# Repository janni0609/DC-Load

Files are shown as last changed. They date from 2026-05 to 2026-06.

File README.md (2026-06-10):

# DC Electronic Load

A programmable DC electronic load built on the Raspberry Pi Pico 2 (RP2350). It sinks a user-defined current from a DC source under test and measures voltage, current, power, capacity, and energy in real time on a colour TFT display.

## Hardware

| Component | Part | Interface |
|---|---|---|
| MCU | Raspberry Pi Pico 2 (RP2350) | — |
| Display | ILI9488 TFT 240×320 | SPI (GPIO 16/18/19/17/20) |
| DAC (current setpoint) | DAC80501 16-bit | I2C1 0x48 |
| ADC (V + I measurement) | ADS1115 16-bit | I2C1 0x49 |
| I/O expander (buttons/encoder) | TCAL9539 16-bit | I2C1 0x74 |
| Temperature sensors | 3× MCP9700 | ADC (GPIO 26/27/28) |
| Fans | 2× PWM | GPIO 2, 3 (25 kHz) |
| Beeper | — | GPIO 22 |

I2C1 runs on GPIO 14 (SDA) / GPIO 15 (SCL) at 1 MHz.

### Board design

KiCad design files live in [`hardware/`](hardware/):

- [`hardware/PlugInDC Load/`](hardware/PlugInDC%20Load/) — main plug-in board (MCU, DAC/ADC, pass elements, power supply)
- [`hardware/Front Panel/`](hardware/Front%20Panel/) — front panel board

Each project includes the schematic, PCB layout, a schematic PDF, and a STEP model.

## Specifications

| Parameter | Range |
|---|---|
| Input voltage | 0 – 100 V |
| Set current | 0 – 100 A |
| Under-voltage / CV setpoint (UVP) | 0 – 99.99 V |
| Max power (beeper threshold) | 1000 W |

The DAC output (0–2.5 V) drives the current-control circuit: 2.5 V = 100 A full scale. The ADS1115 uses auto-ranging PGA for both channels, scaling 2.5 V → 100 V (voltage) and 2.5 V → 100 A (current).

## Display Layout

Portrait 240×320, divided into sections:

```
┌──────────────────────────┐
│    DC ELECTRONIC LOAD    │  ← green = load ON, yellow = load OFF
├──────────────────────────┤
│ VOLTAGE          xx.xx V │
├──────────────────────────┤
│ CURRENT         x.xxx A  │
├──────────────────────────┤
│ POWER           xxx.xx W │
├──────────────┬───────────┤
│ CAPACITY x.xxx Ah │ x.xx Wh ENERGY │
├──────────────┬───────────┤
│ SET CURR x.x A │ SET UVP xx.xx V │  ← UVP turns red in CV mode
├──────────────┬───────────┤
│ TEMP  xx.x°C │ HH:MM:SS  │
└──────────────┴───────────┘
```

## Controls

All buttons and the rotary encoder are read via the TCAL9539 I/O expander. Button behaviour is context-sensitive: the main screen, debug screen, and calibration screens each respond differently.

### Main screen

| Input | Function |
|---|---|
| Rotary encoder | Increment/decrement the selected digit of the active setpoint |
| P0.0 (encoder push) | Toggle between editing **SET CURR** and **SET UVP** |
| P0.3 | Move cursor left |
| P0.4 | Move cursor right |
| P0.5 | Switch to debug screen |
| P0.6 | Reset elapsed timer and clear Ah/Wh accumulators |
| P0.7 | Toggle internal / external voltage sense |
| P1.0 | Load ON / OFF (blocked while OTP is active) |

### Debug screen

The debug screen is a navigable menu. P0.3/P0.4 move the selection, the encoder adjusts the highlighted item, and P0.0 (encoder push) activates it.

| Menu item | Function |
|---|---|
| I SENSE | Toggle internal / external current shunt (persisted to EEPROM) |
| VOLT CAL | Enter voltage calibration wizard |
| CURR CAL | Enter current calibration wizard |
| VIEW CAL | Display stored calibration tables |
| OTP TRIP | Set over-temperature protection threshold with encoder (persisted) |
| UVP Kp | Adjust UVP PI proportional gain with encoder (persisted) |
| UVP Ki | Adjust UVP PI integral gain with encoder (persisted) |

### Calibration screen

| Input | Function |
|---|---|
| Rotary encoder | Adjust the entered reference value |
| P0.3 / P0.4 | Move digit cursor left / right |
| P0.0 (encoder push) | Confirm step and advance |
| P0.5 | Cancel and return to debug screen |

## UVP / Constant-Voltage Mode

When **SET UVP** is non-zero and the load is on, a software PI controller monitors the measured voltage. If it drops below the UVP setpoint, the controller reduces the sink current to regulate voltage at that level (constant-voltage / CV mode). The SET UVP field turns red while CV mode is active.

CV mode exits with 0.5 V hysteresis to avoid chattering. The PI gains (Kp, Ki) are tunable from the debug screen and stored in EEPROM.

## Over-Temperature Protection (OTP)

The OTP threshold (default 70 °C, adjustable 30–120 °C) is compared against the highest reading across all three MCP9700 sensors. When the threshold is exceeded:

- The load is turned off immediately.
- Five 500 ms beeps are sounded.
- The load ON button is blocked until the temperature drops 5 °C below the threshold.

## Fan Control

Fan speed is temperature-controlled using the highest reading across all three MCP9700 sensors:

- Off below 30 °C
- Linear ramp from 0–100 % between 30 °C and 50 °C
- Full speed above 50 °C

## Calibration

Both voltage and current channels support piecewise-linear calibration (4 points for voltage, 5 for current). The calibration wizard drives the load to each reference point, reads the raw ADC value, and prompts for the reference meter reading. Calibration data is stored in EEPROM and applied on every measurement via `piecewiseLerp`.

### EEPROM layout

| Address | Content |
|---|---|
| 0 | Current shunt select (0x01 = external) |
| 1 | Current cal valid marker (0xCA) |
| 2 | Voltage cal valid marker (0xCA) |
| 3–42 | Current cal: 5× raw + 5× user (10 floats) |
| 43–74 | Voltage cal: 4× raw + 4× user (8 floats) |
| 75 | OTP valid marker (0xCA) |
| 76–79 | OTP threshold (float) |
| 80 | UVP PI valid marker (0xCA) |
| 81–84 | UVP Kp (float) |
| 85–88 | UVP Ki (float) |

## Building

The project uses [PlatformIO](https://platformio.org/) with the Arduino framework.

```bash
# Build
pio run

# Upload
pio run --target upload

# Serial monitor
pio device monitor --baud 115200
```

Target board: `rpipico2`. Dependencies are fetched automatically (`Bodmer/TFT_eSPI`).

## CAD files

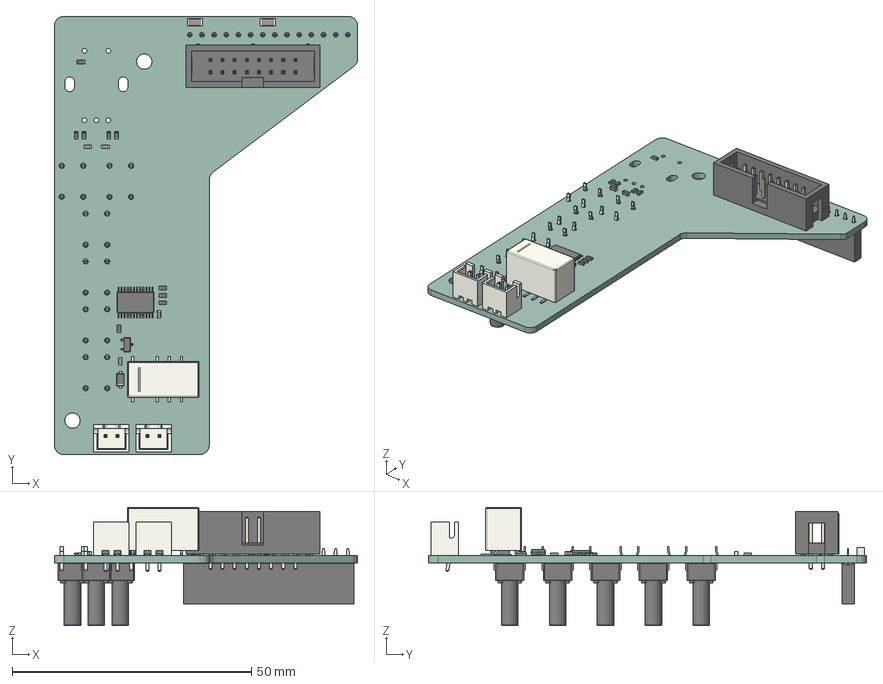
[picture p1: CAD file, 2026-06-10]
hardware/Front Panel/FrontV3.step
63.4 x 91.5 x 24.7 mm
R_0603_1608Metric x 9
JST_XH_B2B-XH-A_1x02_P2.50mm_Vertical x 2
IDC-Header_2x08_P2.54mm_Vertical
C_0603_1608Metric x 4
Relay_DPDT_Kemet_EE2_NU
C_1206_3216Metric x 2
SOT-23
D_SOD-123F
TSSOP-24_4.4x7.8mm_P0.65mm
SW_PUSH_6mm_H13mm x 6
PinSocket_1x14_P2.54mm_Vertical
Front Panel_PCB

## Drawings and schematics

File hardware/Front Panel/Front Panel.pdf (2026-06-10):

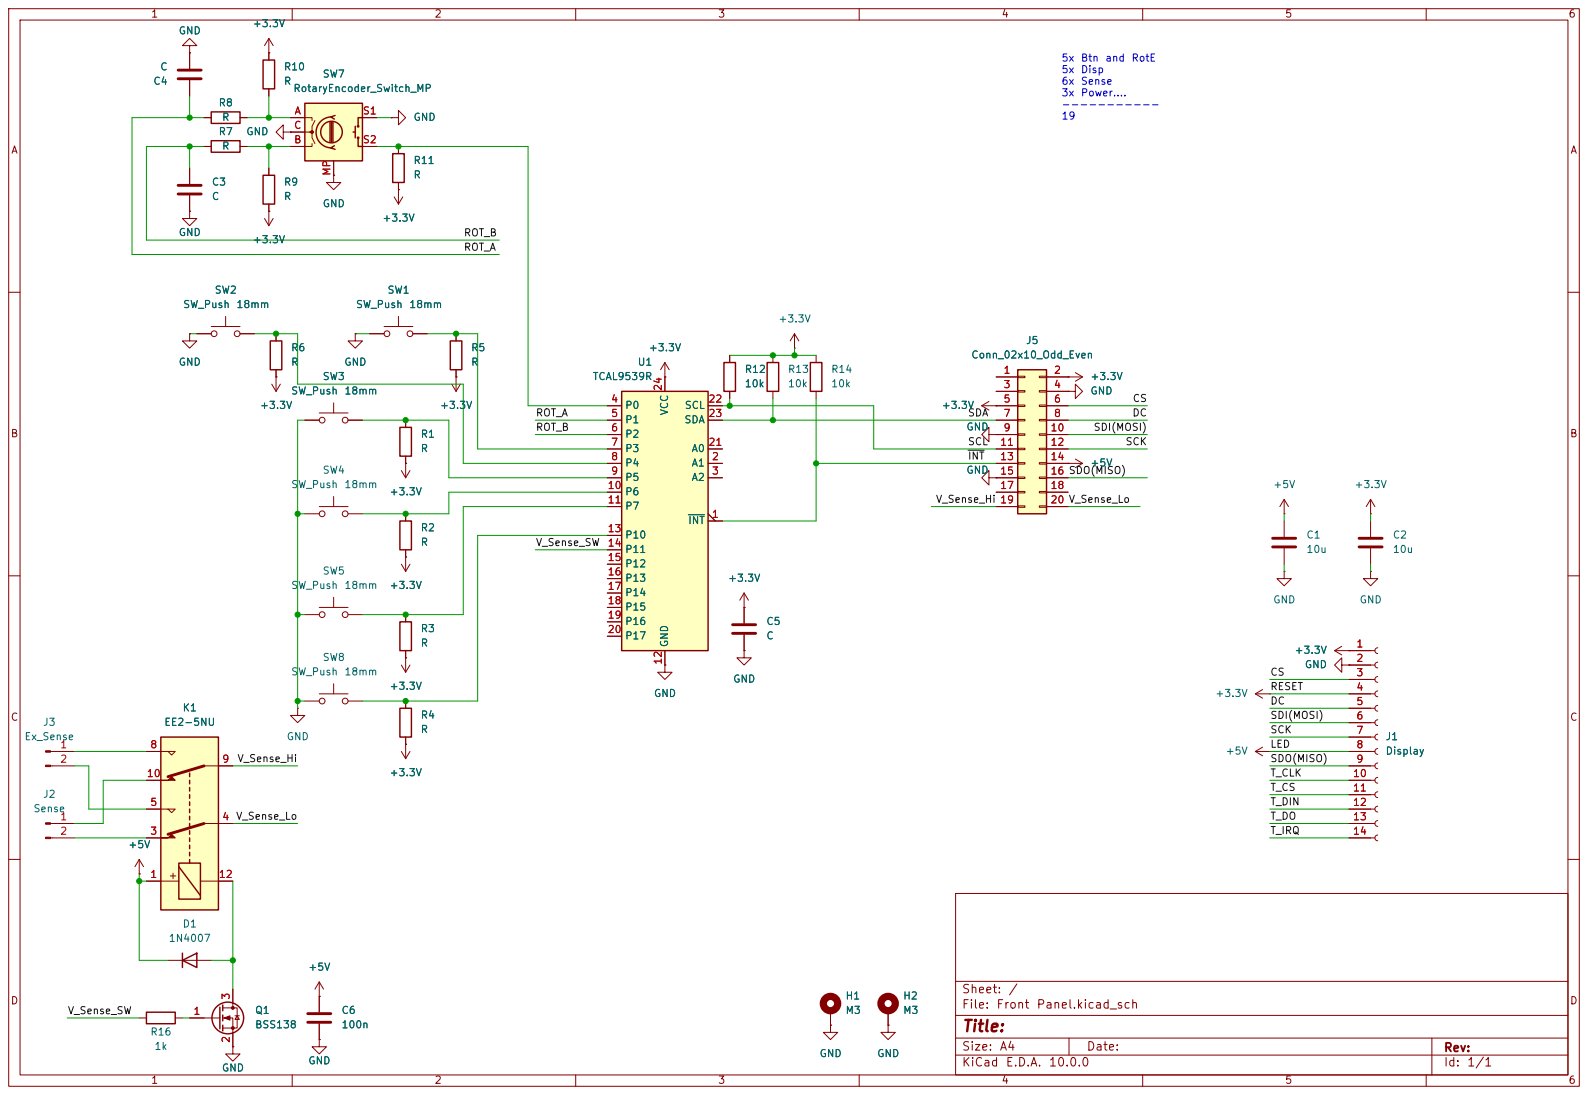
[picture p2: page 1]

5x Btn and RotE 5x Disp

Size: A4 | Rev:
KiCad E.D.A. 10.0.0 | Id: 1/1

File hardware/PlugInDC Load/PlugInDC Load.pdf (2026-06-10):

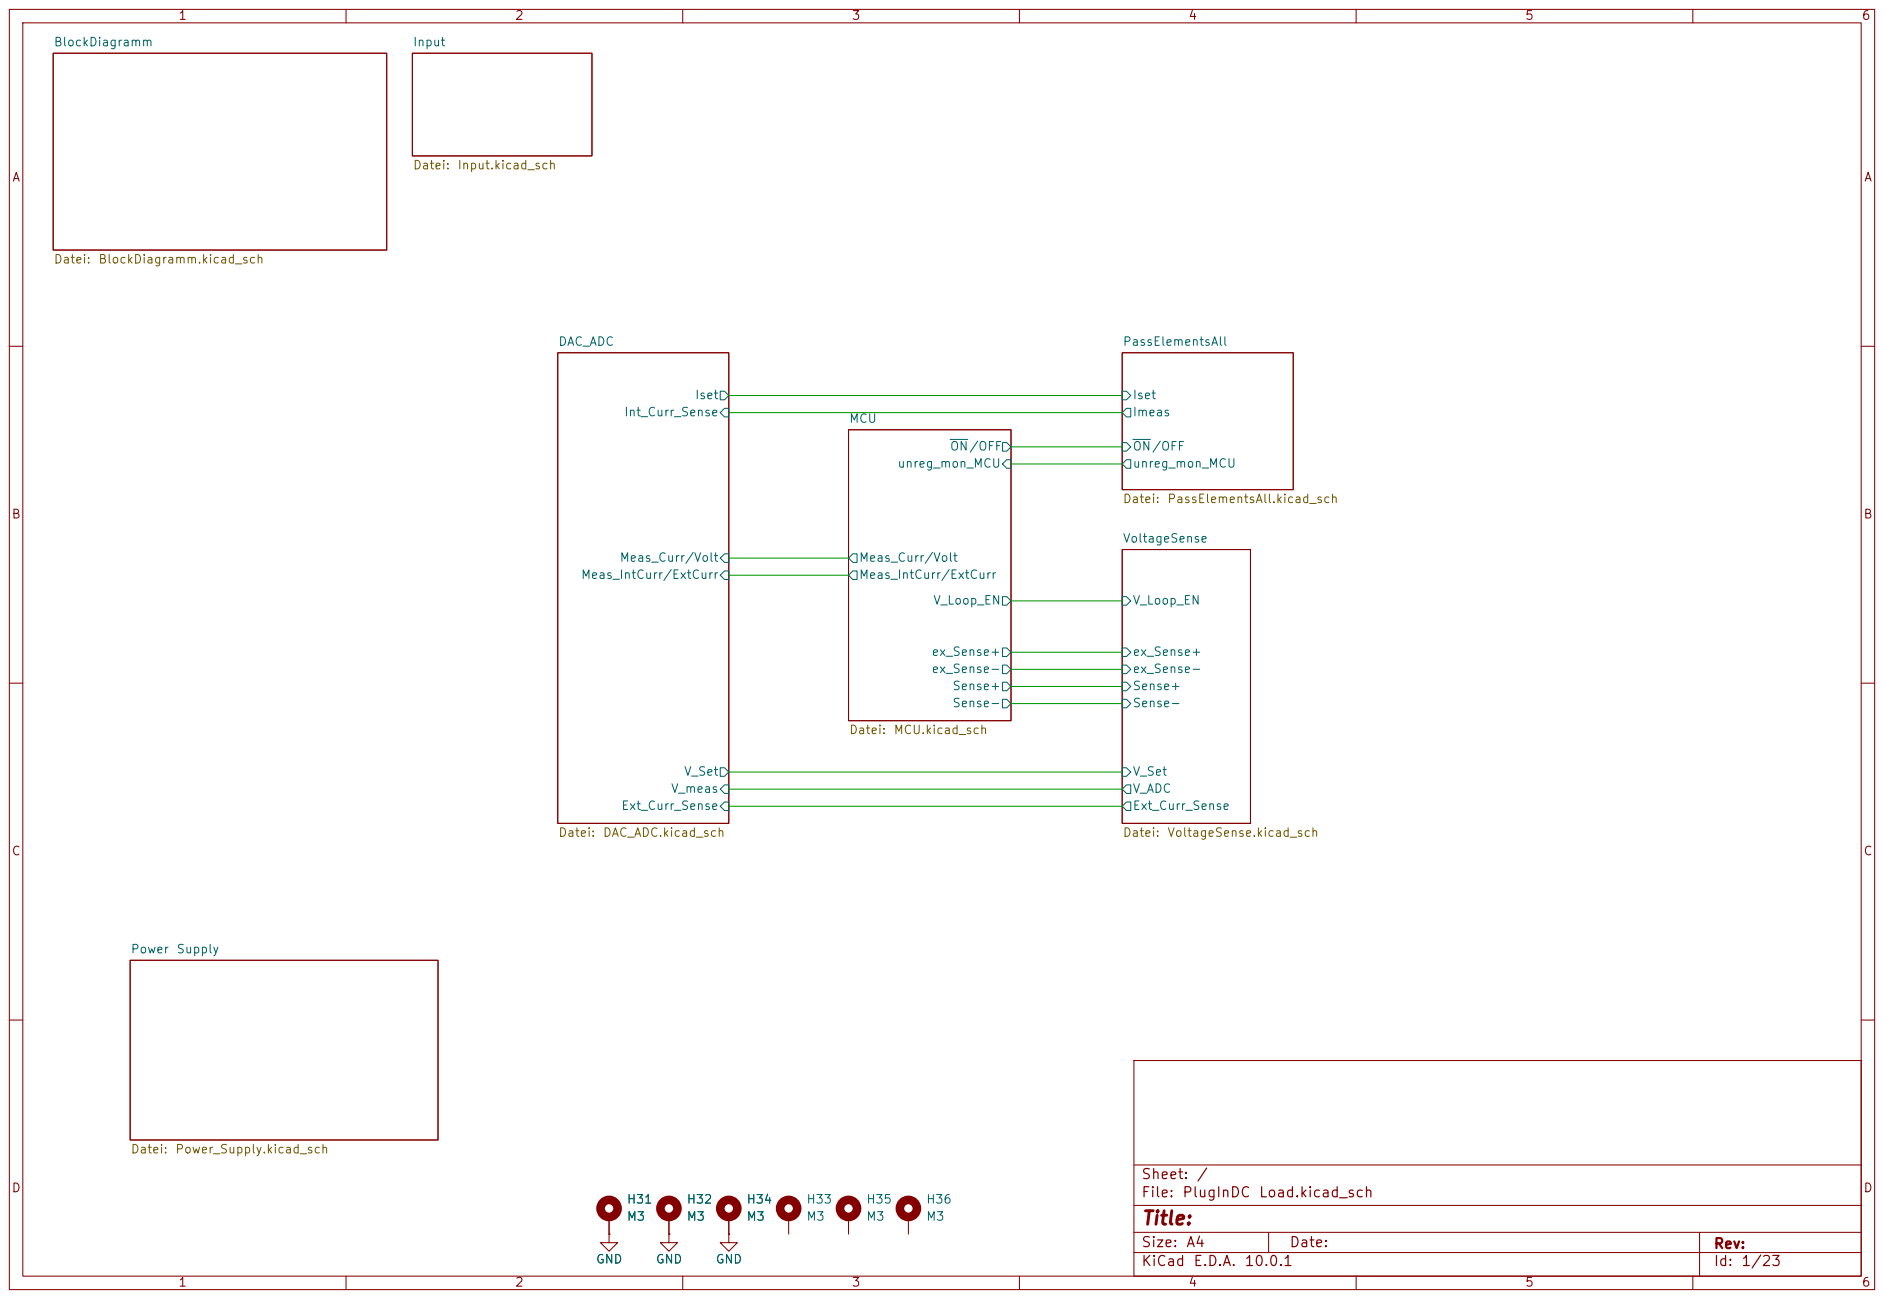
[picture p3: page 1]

PassElementsAll Datei: PassElementsAll.kicad_sch Power Supply Datei: Power_Supply.kicad_sch

Size: A4 | Rev:
KiCad E.D.A. 10.0.1 | Id: 1/23

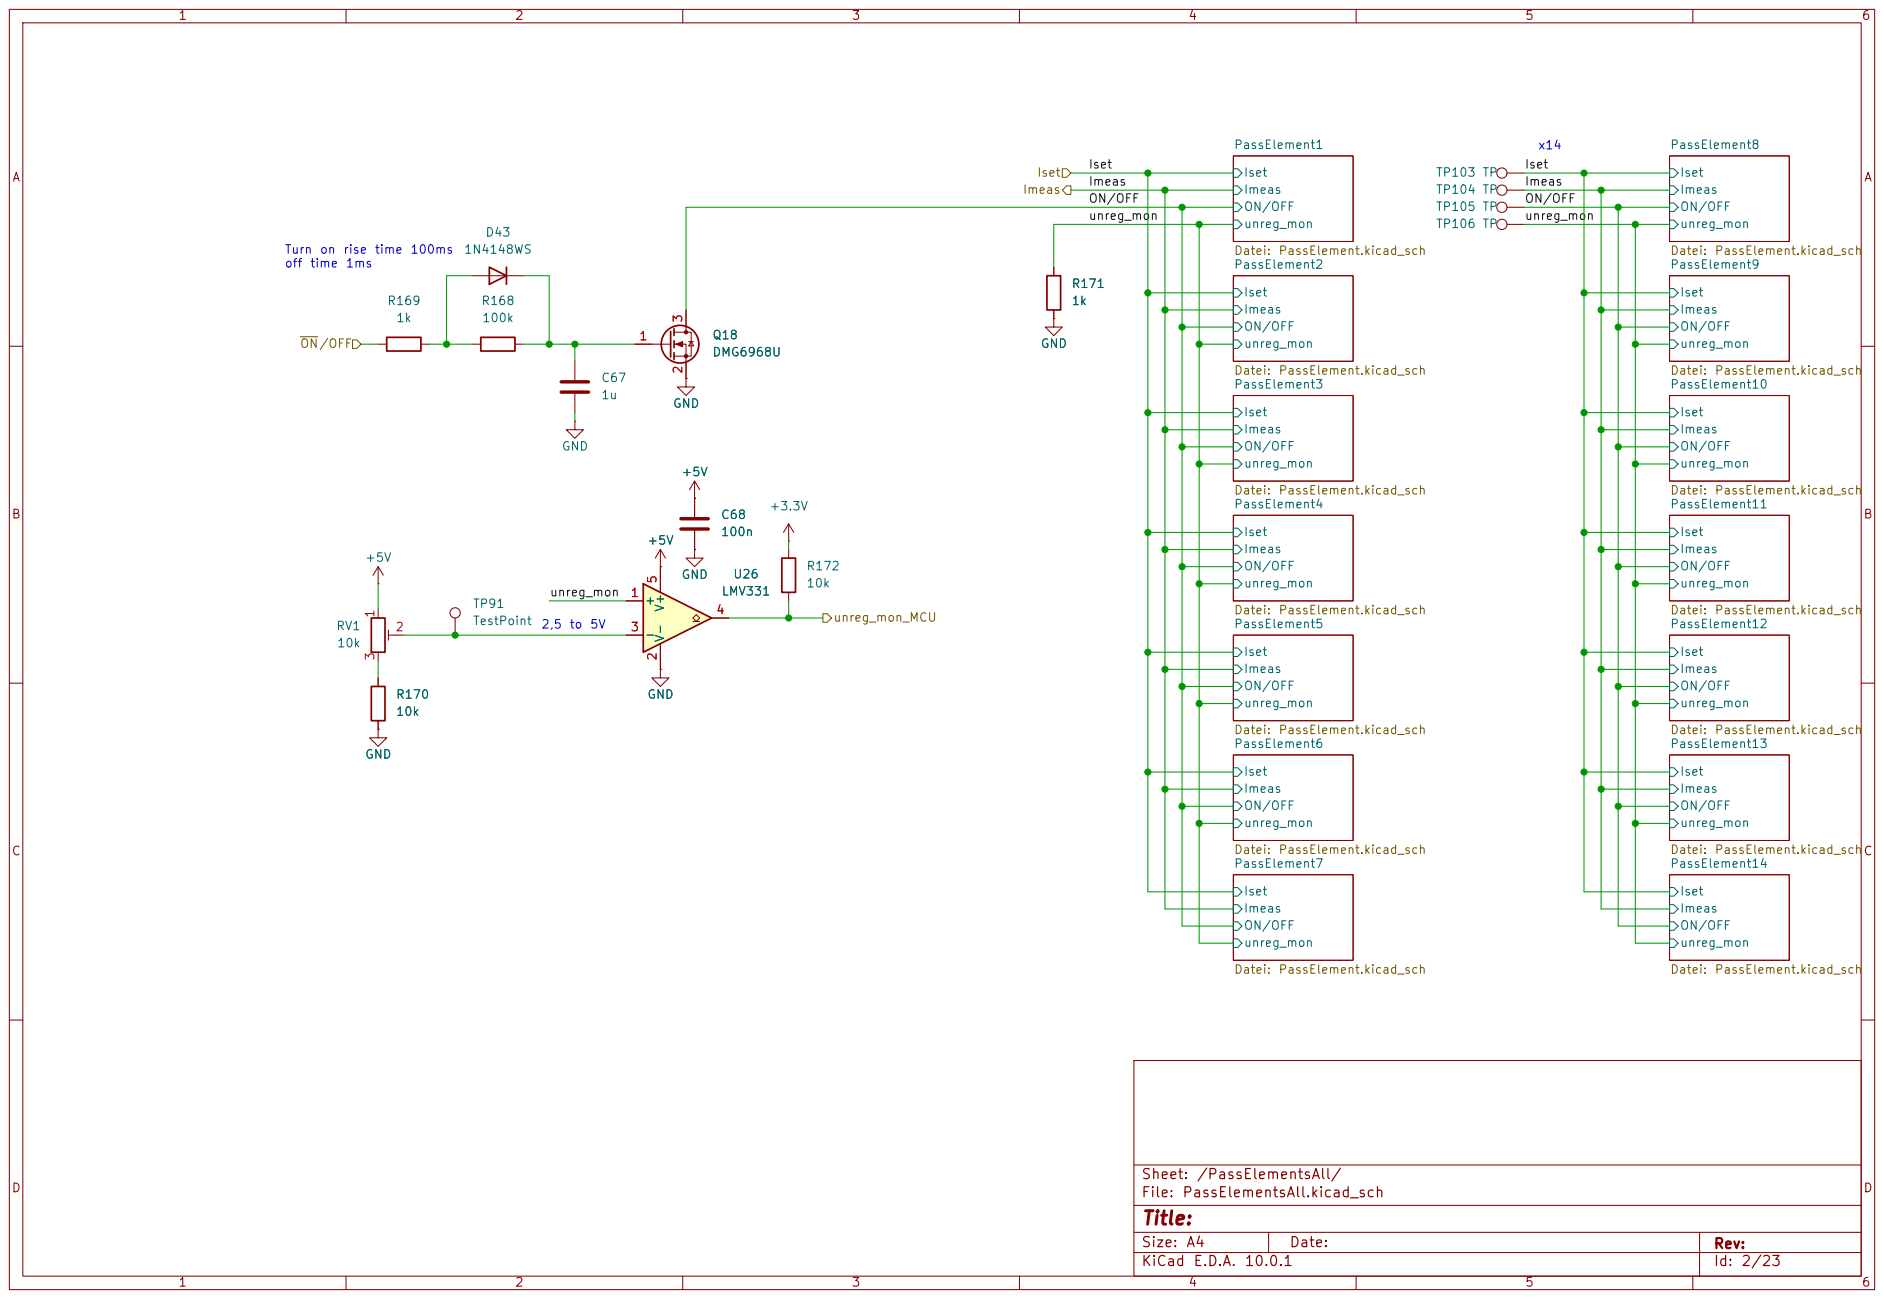
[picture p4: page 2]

Iset ON/OFF unreg_mon PassElement1 Datei: PassElement.kicad_sch
Iset unreg_mon_MCU

Iset ON/OFF unreg_mon PassElement8 Datei: PassElement.kicad_sch

Iset ON/OFF unreg_mon PassElement12 Datei: PassElement.kicad_sch D43

Iset ON/OFF unreg_mon PassElement2 Datei: PassElement.kicad_sch

Iset ON/OFF unreg_mon PassElement9 Datei: PassElement.kicad_sch

Iset ON/OFF unreg_mon PassElement3 Datei: PassElement.kicad_sch

Iset ON/OFF unreg_mon PassElement10 Datei: PassElement.kicad_sch

Iset ON/OFF unreg_mon PassElement4 Datei: PassElement.kicad_sch

Iset ON/OFF unreg_mon PassElement11 Datei: PassElement.kicad_sch

Iset ON/OFF unreg_mon PassElement5 Datei: PassElement.kicad_sch

Iset ON/OFF unreg_mon PassElement6 Datei: PassElement.kicad_sch

Iset ON/OFF unreg_mon PassElement13 Datei: PassElement.kicad_sch

Iset ON/OFF unreg_mon PassElement7 Datei: PassElement.kicad_sch

Iset ON/OFF unreg_mon PassElement14 Datei: PassElement.kicad_sch

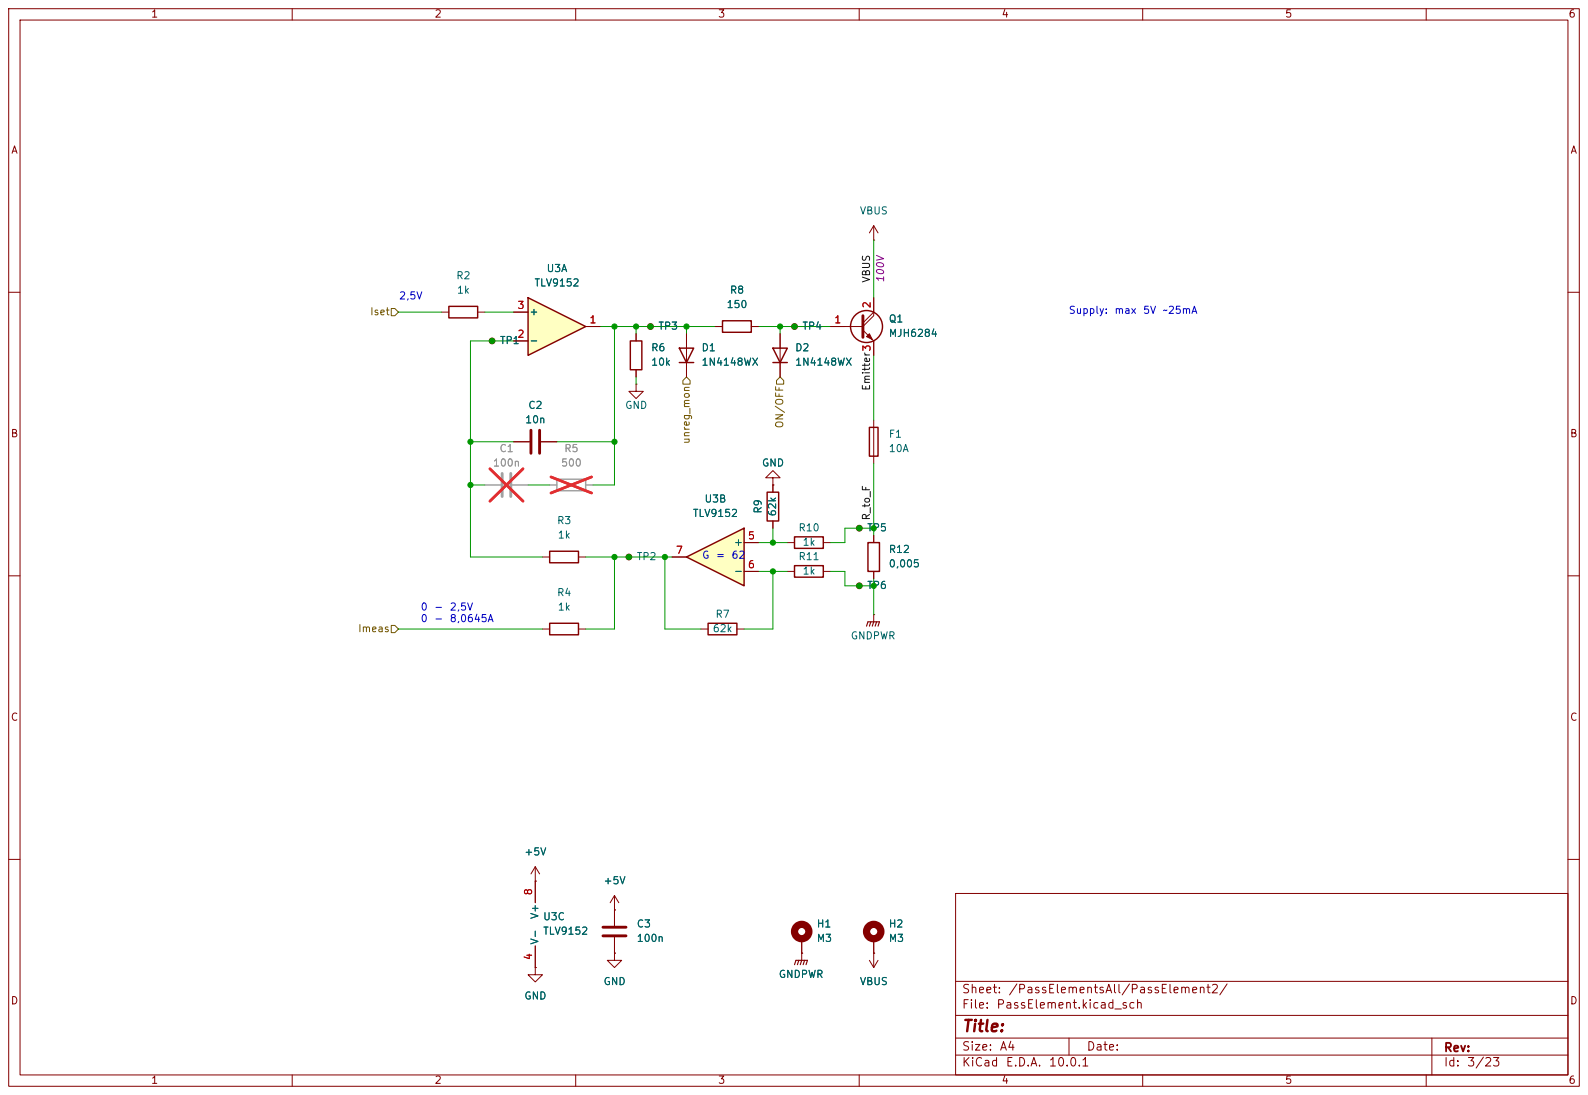
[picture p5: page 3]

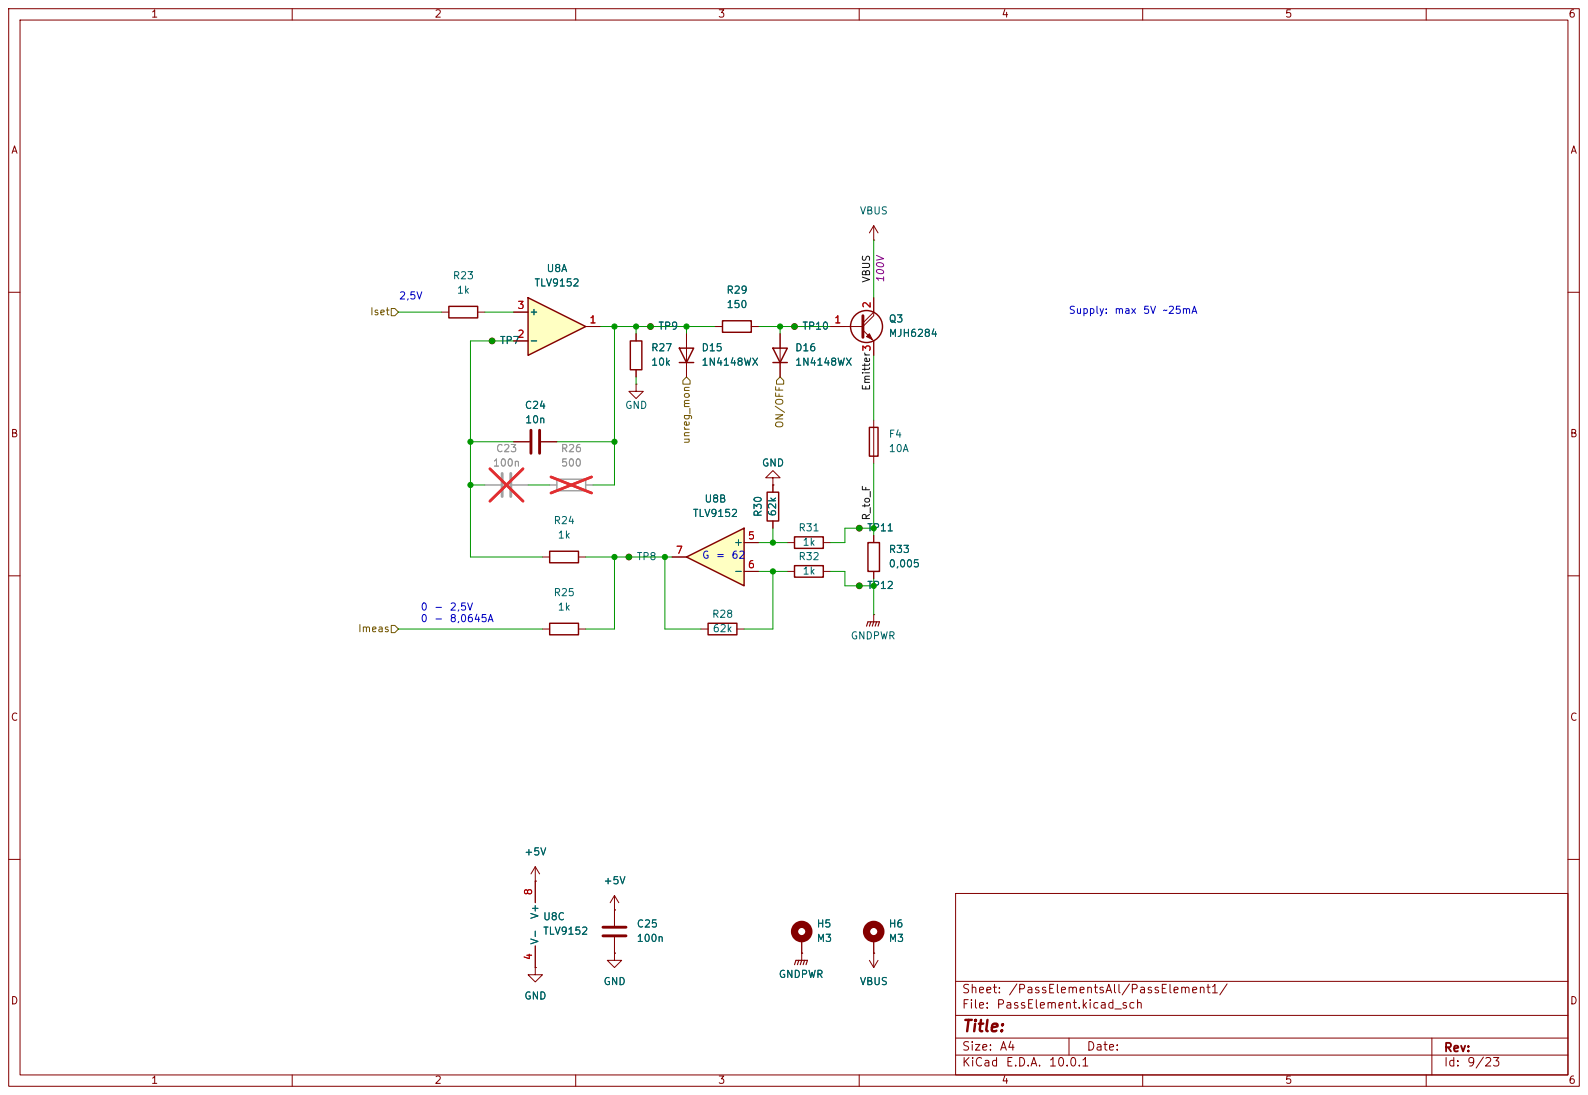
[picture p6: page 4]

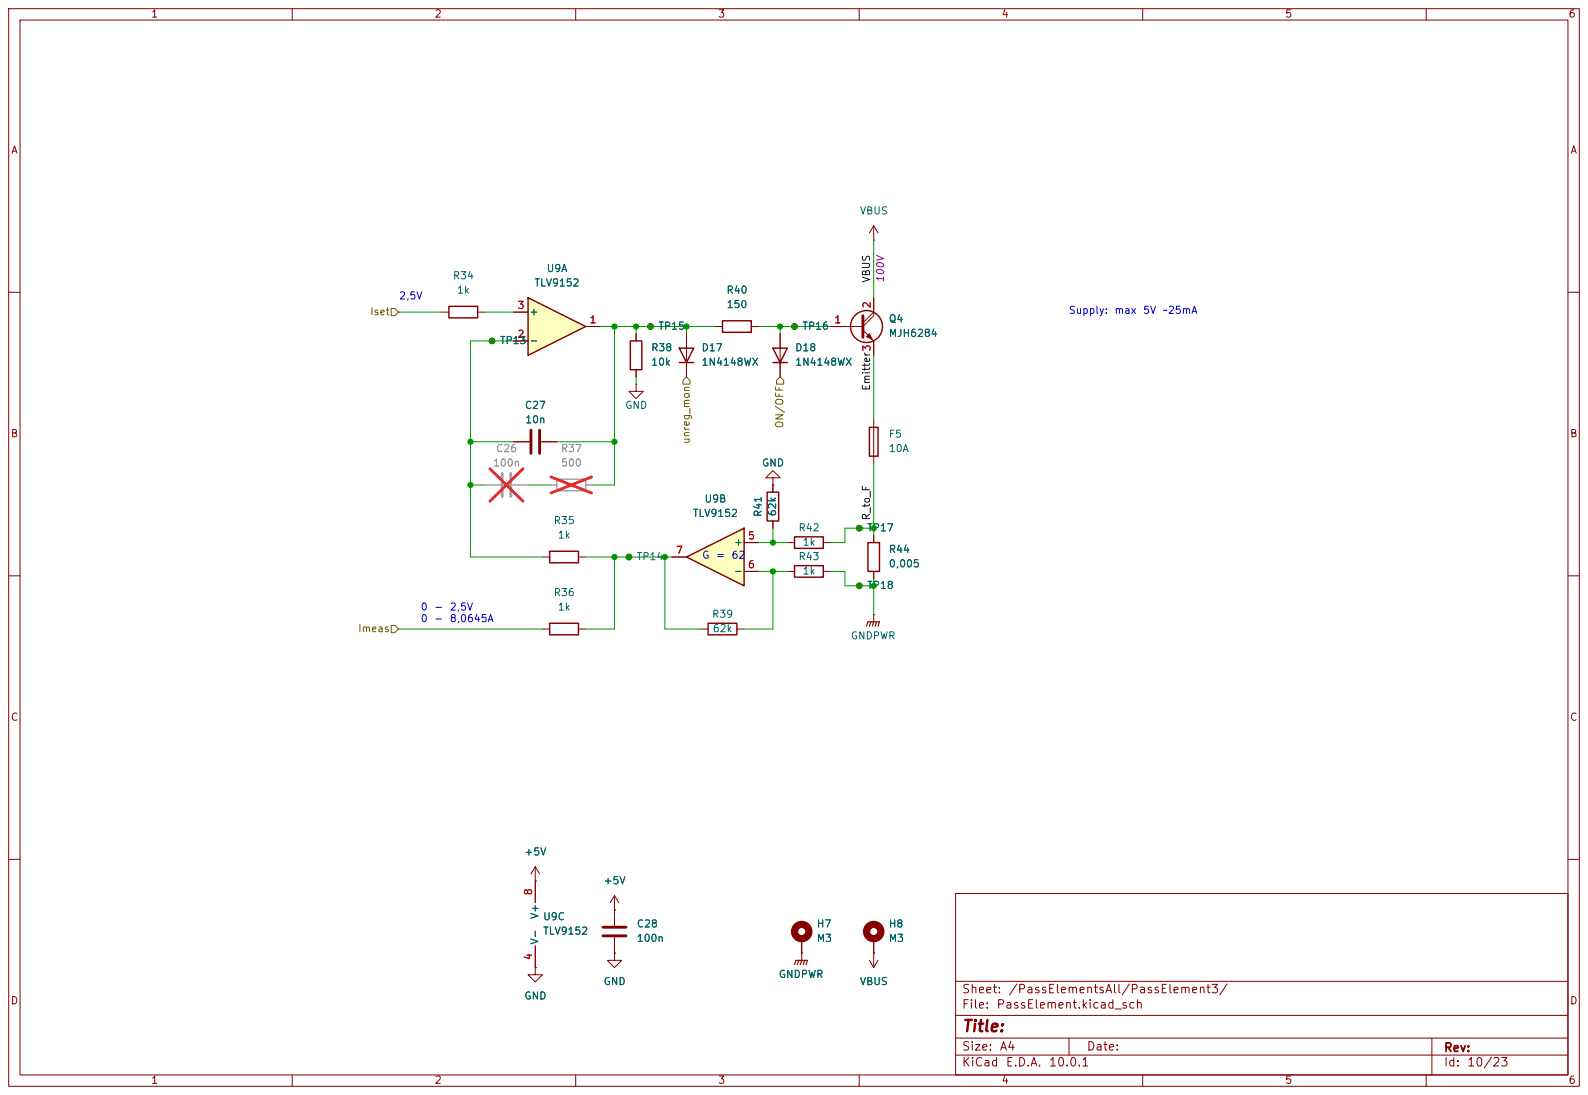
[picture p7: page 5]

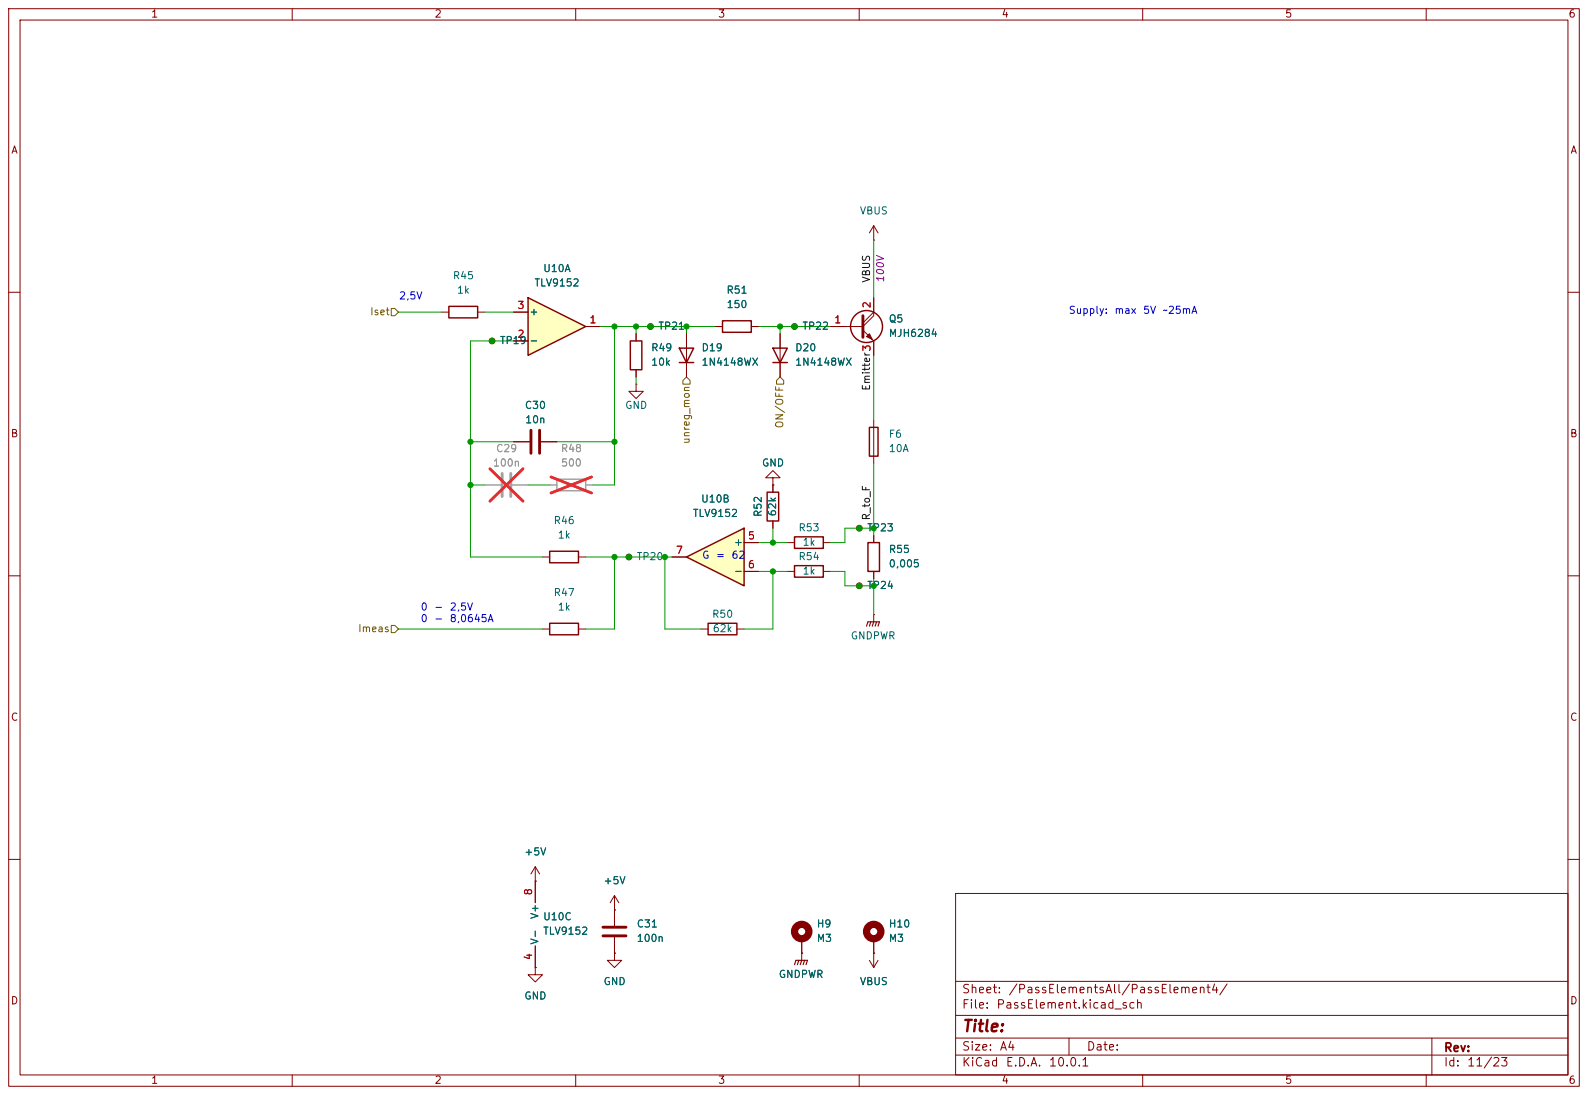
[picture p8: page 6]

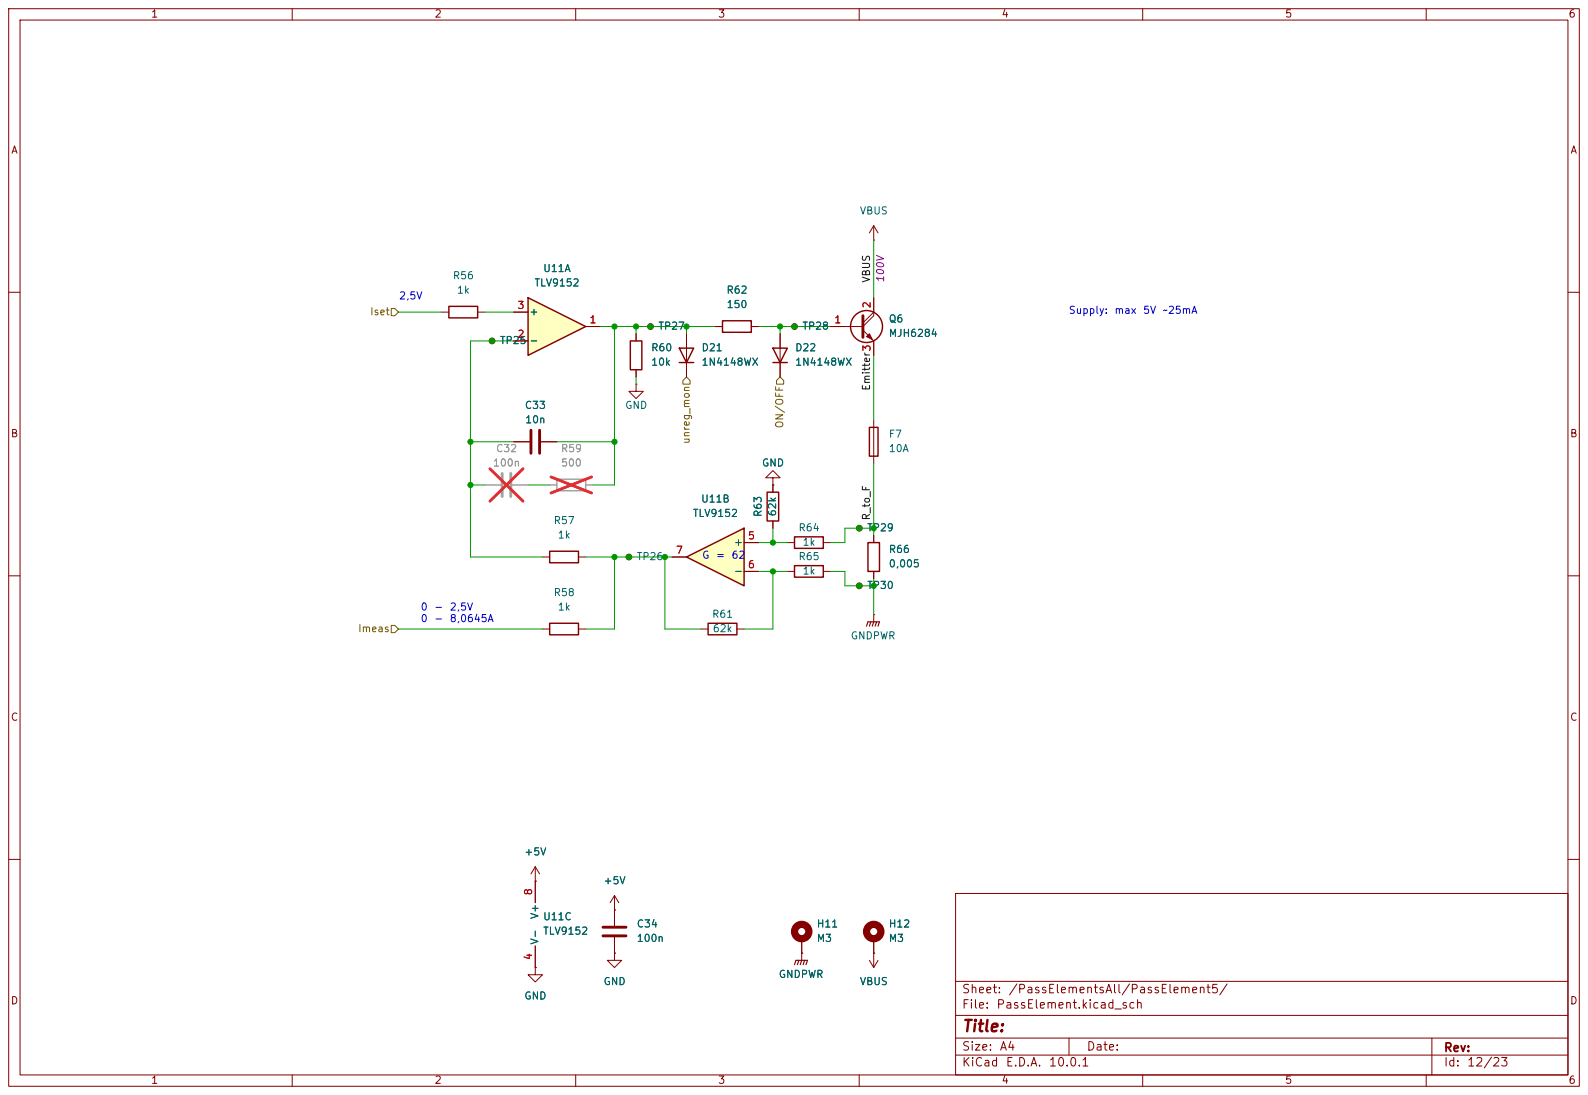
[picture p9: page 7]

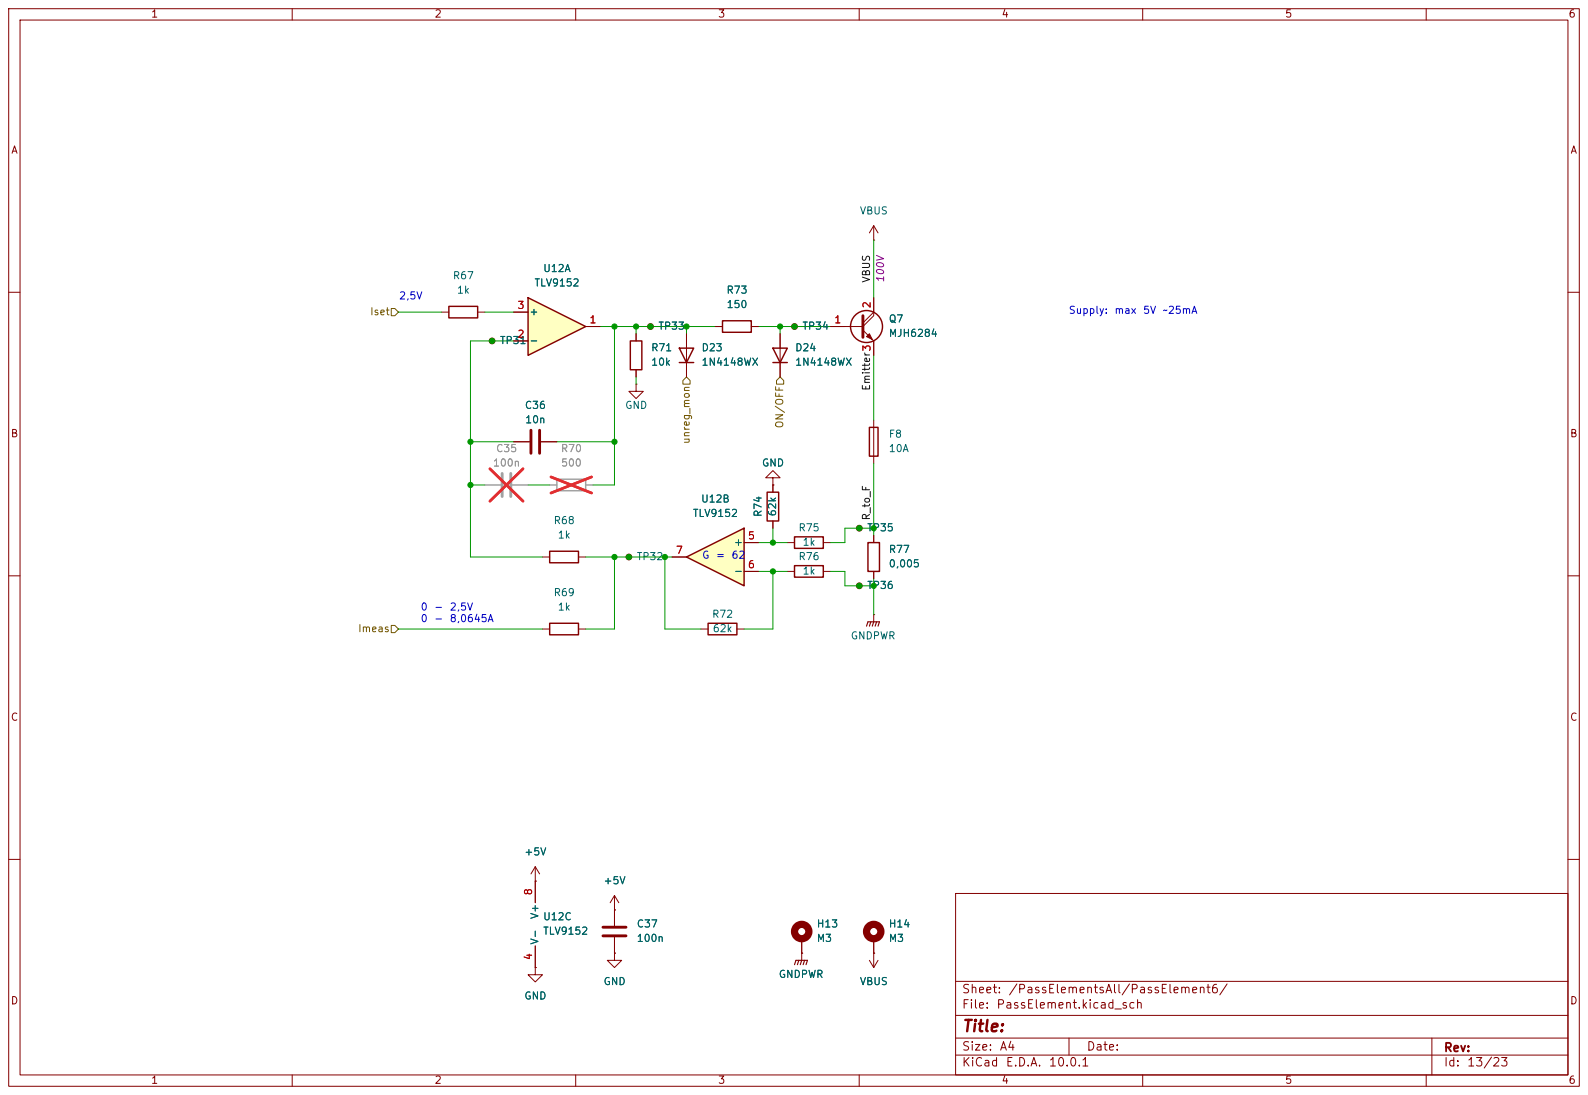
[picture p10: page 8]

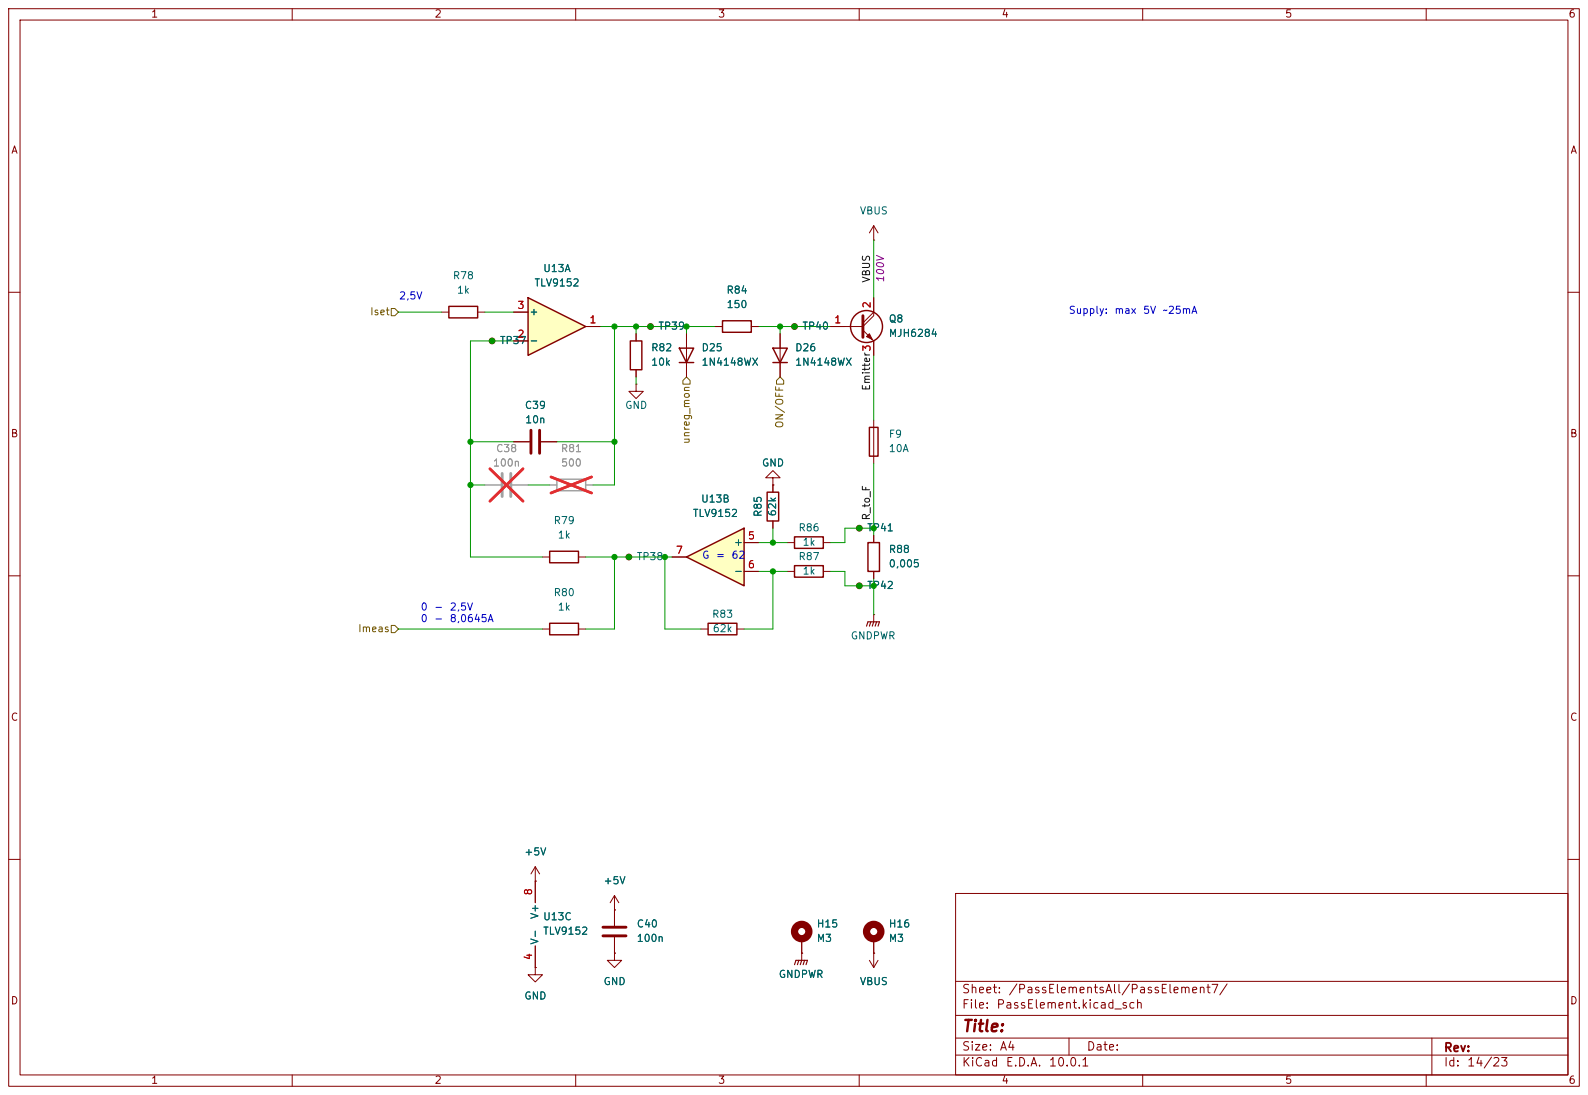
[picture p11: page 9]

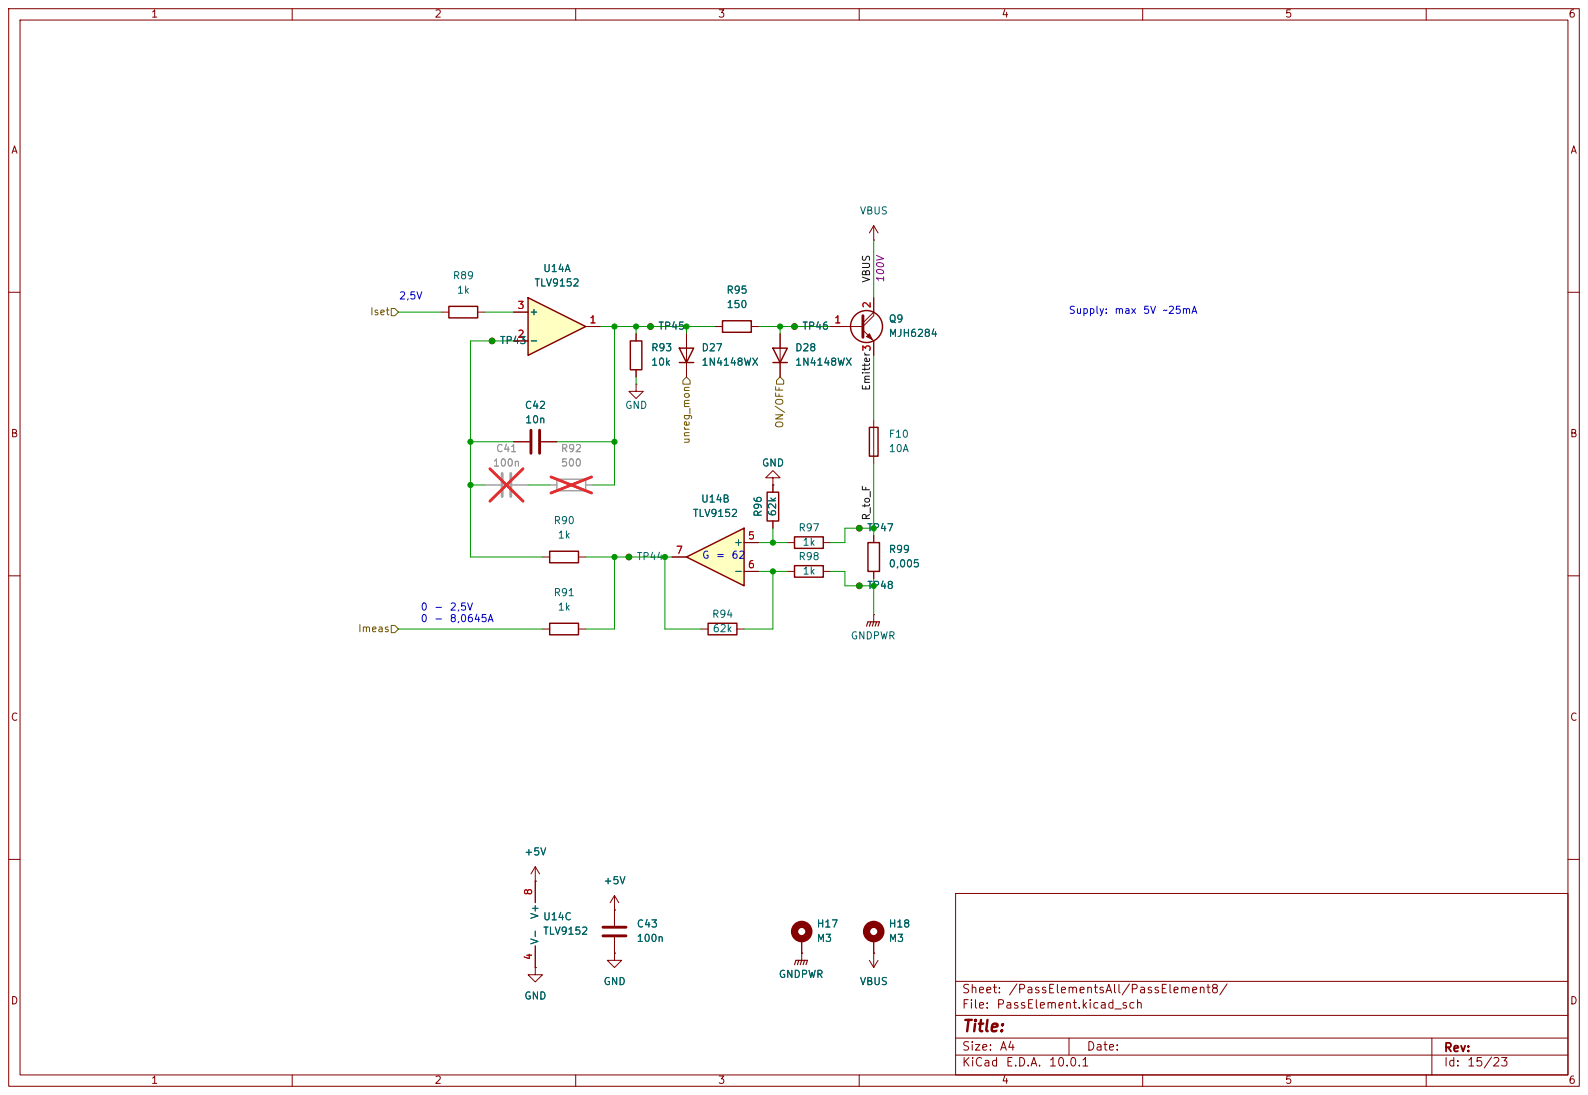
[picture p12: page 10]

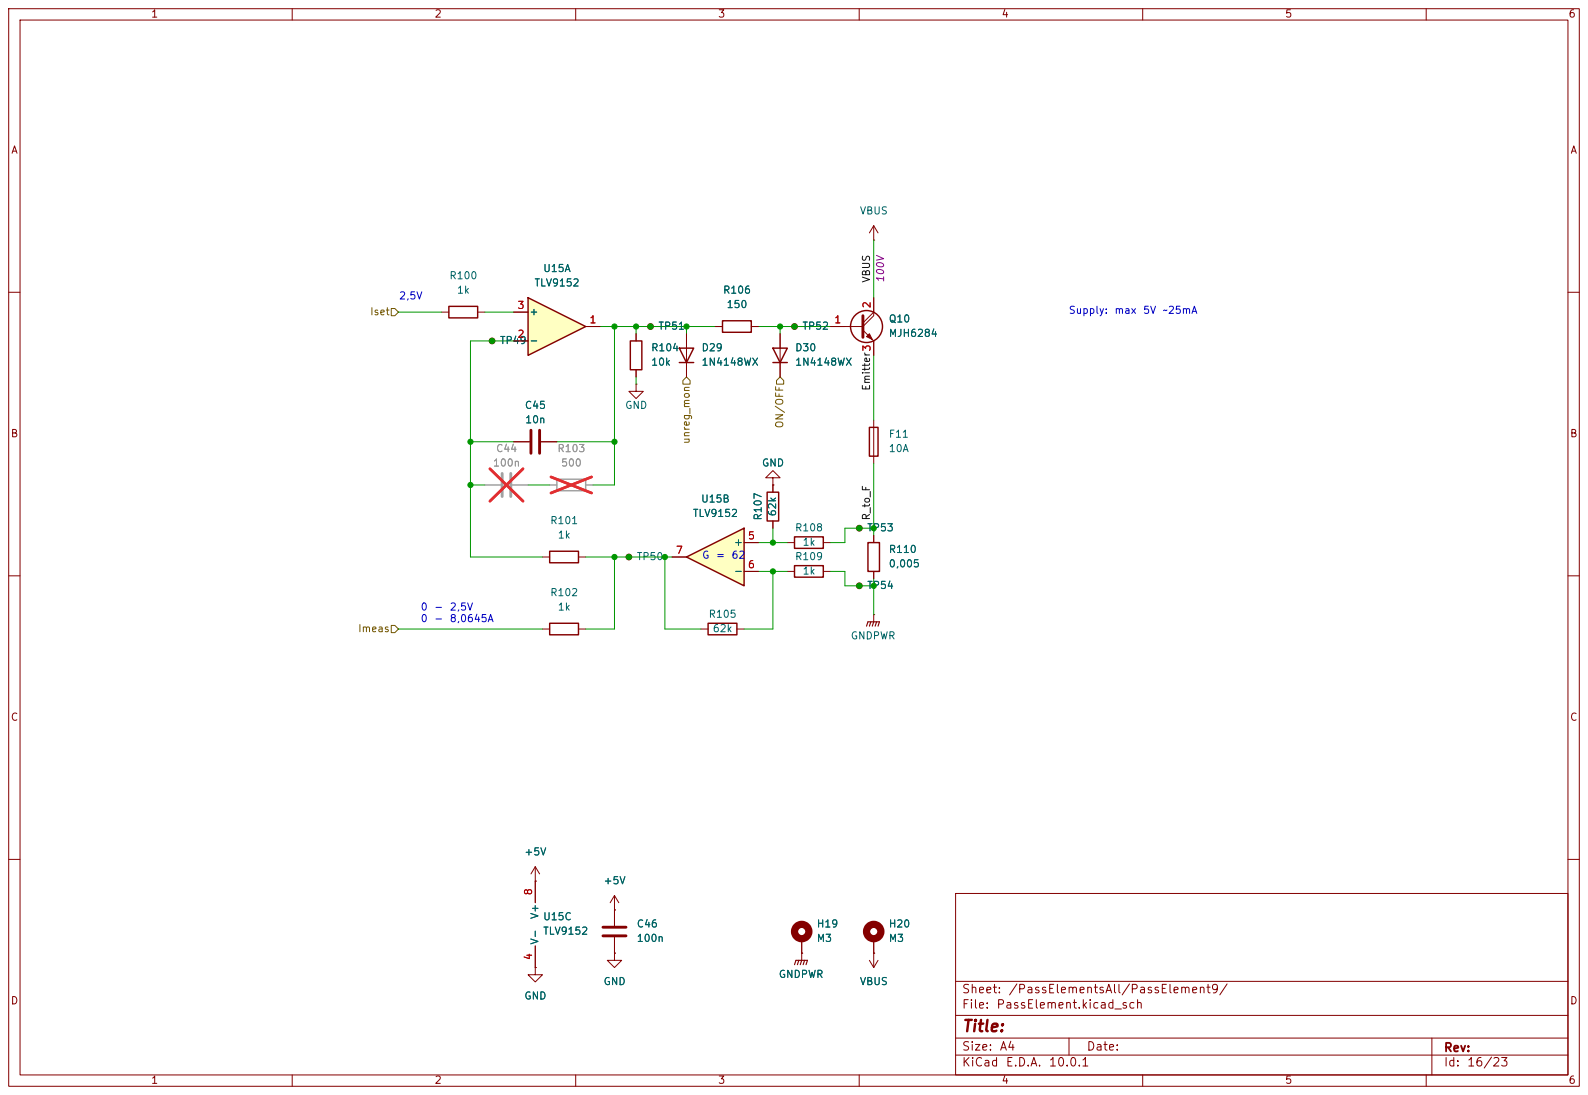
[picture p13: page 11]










Sheet: /Power Supply/ GND


Sheet: /Power Supply/AP63200-DCDC/
File: AP63200-DCDC.kicad_sch
Title:



Int_Curr_Sense SDA SCL SCL SDA

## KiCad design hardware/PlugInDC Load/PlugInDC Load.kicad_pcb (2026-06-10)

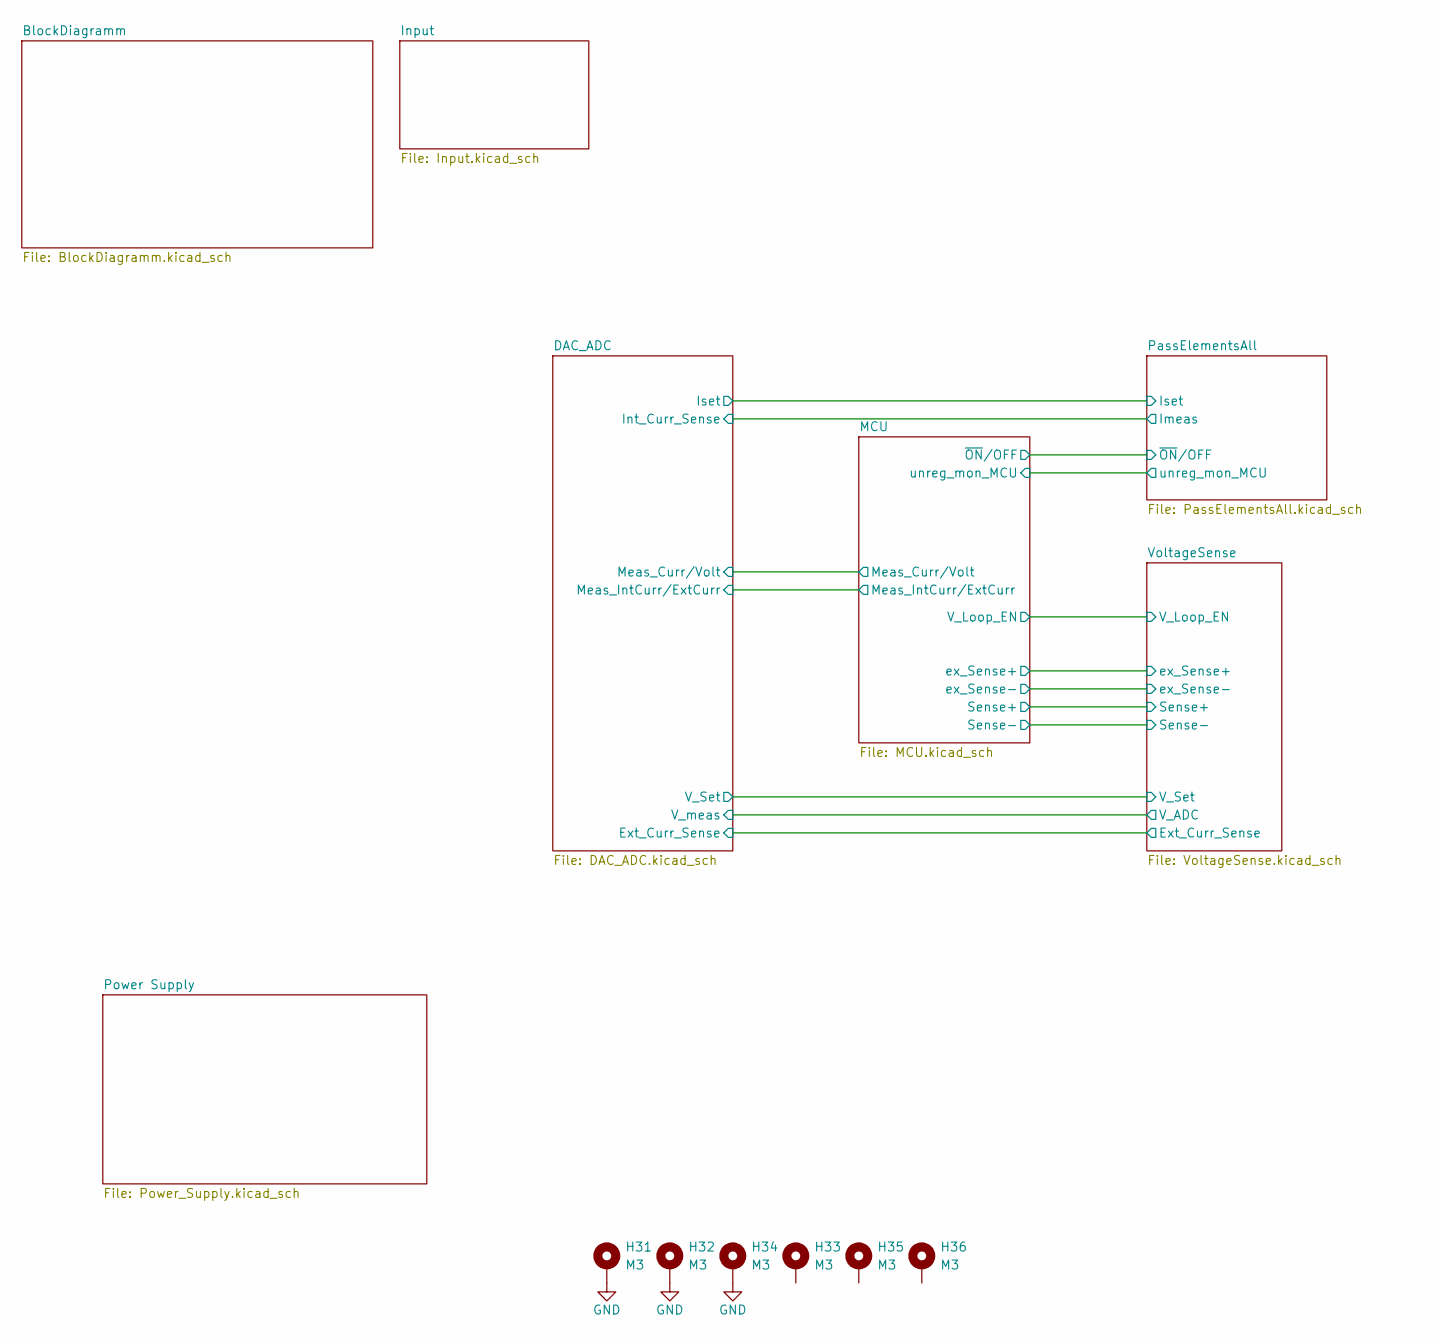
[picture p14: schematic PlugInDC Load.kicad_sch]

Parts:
H31, H32, H33, H34, H35, H36: M3; MountingHole_3.2mm_M3_DIN965_Pad

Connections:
GND: H31.1 (1_1), H32.1 (1_1), H34.1 (1_1); also elsewhere on the board

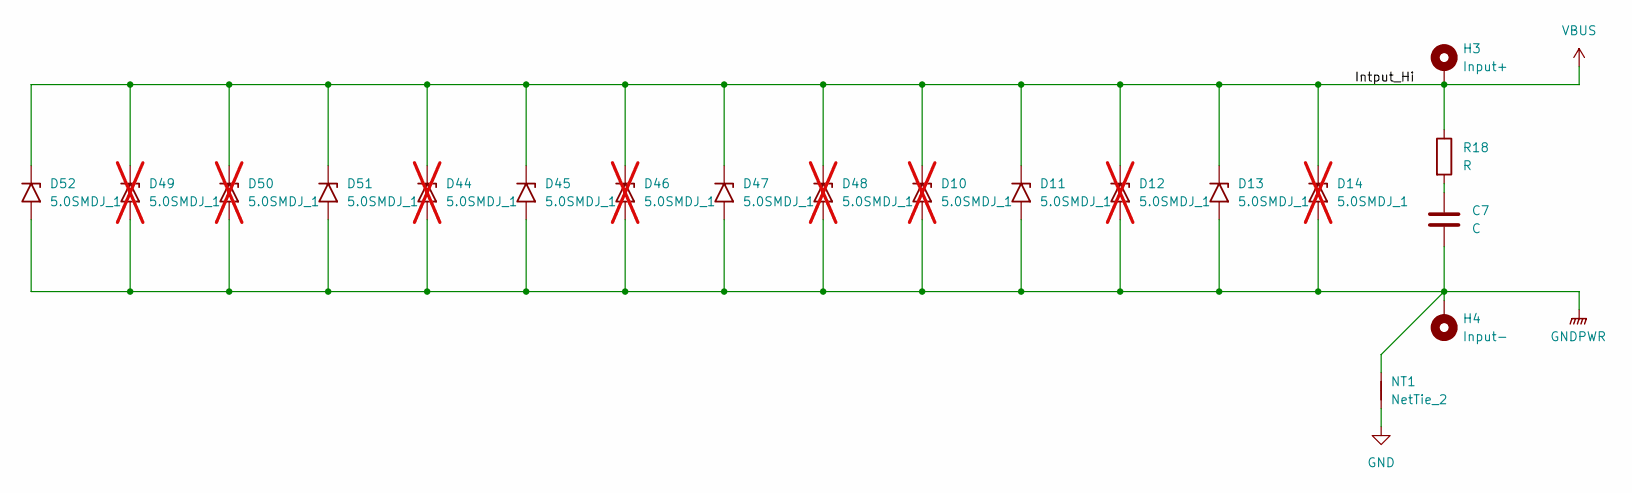
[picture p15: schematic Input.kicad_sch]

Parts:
C7: C; C_1206_3216Metric
D10, D12, D14, D44, D46, D48, D49, D50: 5.0SMDJ_1; D_SMC; not fitted
D11, D13, D45, D47, D51, D52: 5.0SMDJ_1; D_SMC
H3: Input+; MountingHole_4.3mm_M4_DIN965_Pad
H4: Input-; MountingHole_4.3mm_M4_DIN965_Pad
NT1: NetTie_2; NetTie-2_SMD_Pad2.0mm
R18: R; R_1206_3216Metric

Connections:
GND: NT1.1; also elsewhere on the board
GNDPWR: C7.2, D10.2 (A2), D11.2 (A2), D12.2 (A2), D13.2 (A2), D14.2 (A2), D44.2 (A2), D45.2 (A2), D46.2 (A2), D47.2 (A2), D48.2 (A2), D49.2 (A2), D50.2 (A2), D51.2 (A2), D52.2 (A2), H4.1 (1_1), NT1.2; also elsewhere on the board
unnamed: C7.1, R18.2
VBUS: D10.1 (A1), D11.1 (A1), D12.1 (A1), D13.1 (A1), D14.1 (A1), D44.1 (A1), D45.1 (A1), D46.1 (A1), D47.1 (A1), D48.1 (A1), D49.1 (A1), D50.1 (A1), D51.1 (A1), D52.1 (A1), H3.1 (1_1), R18.1; also elsewhere on the board

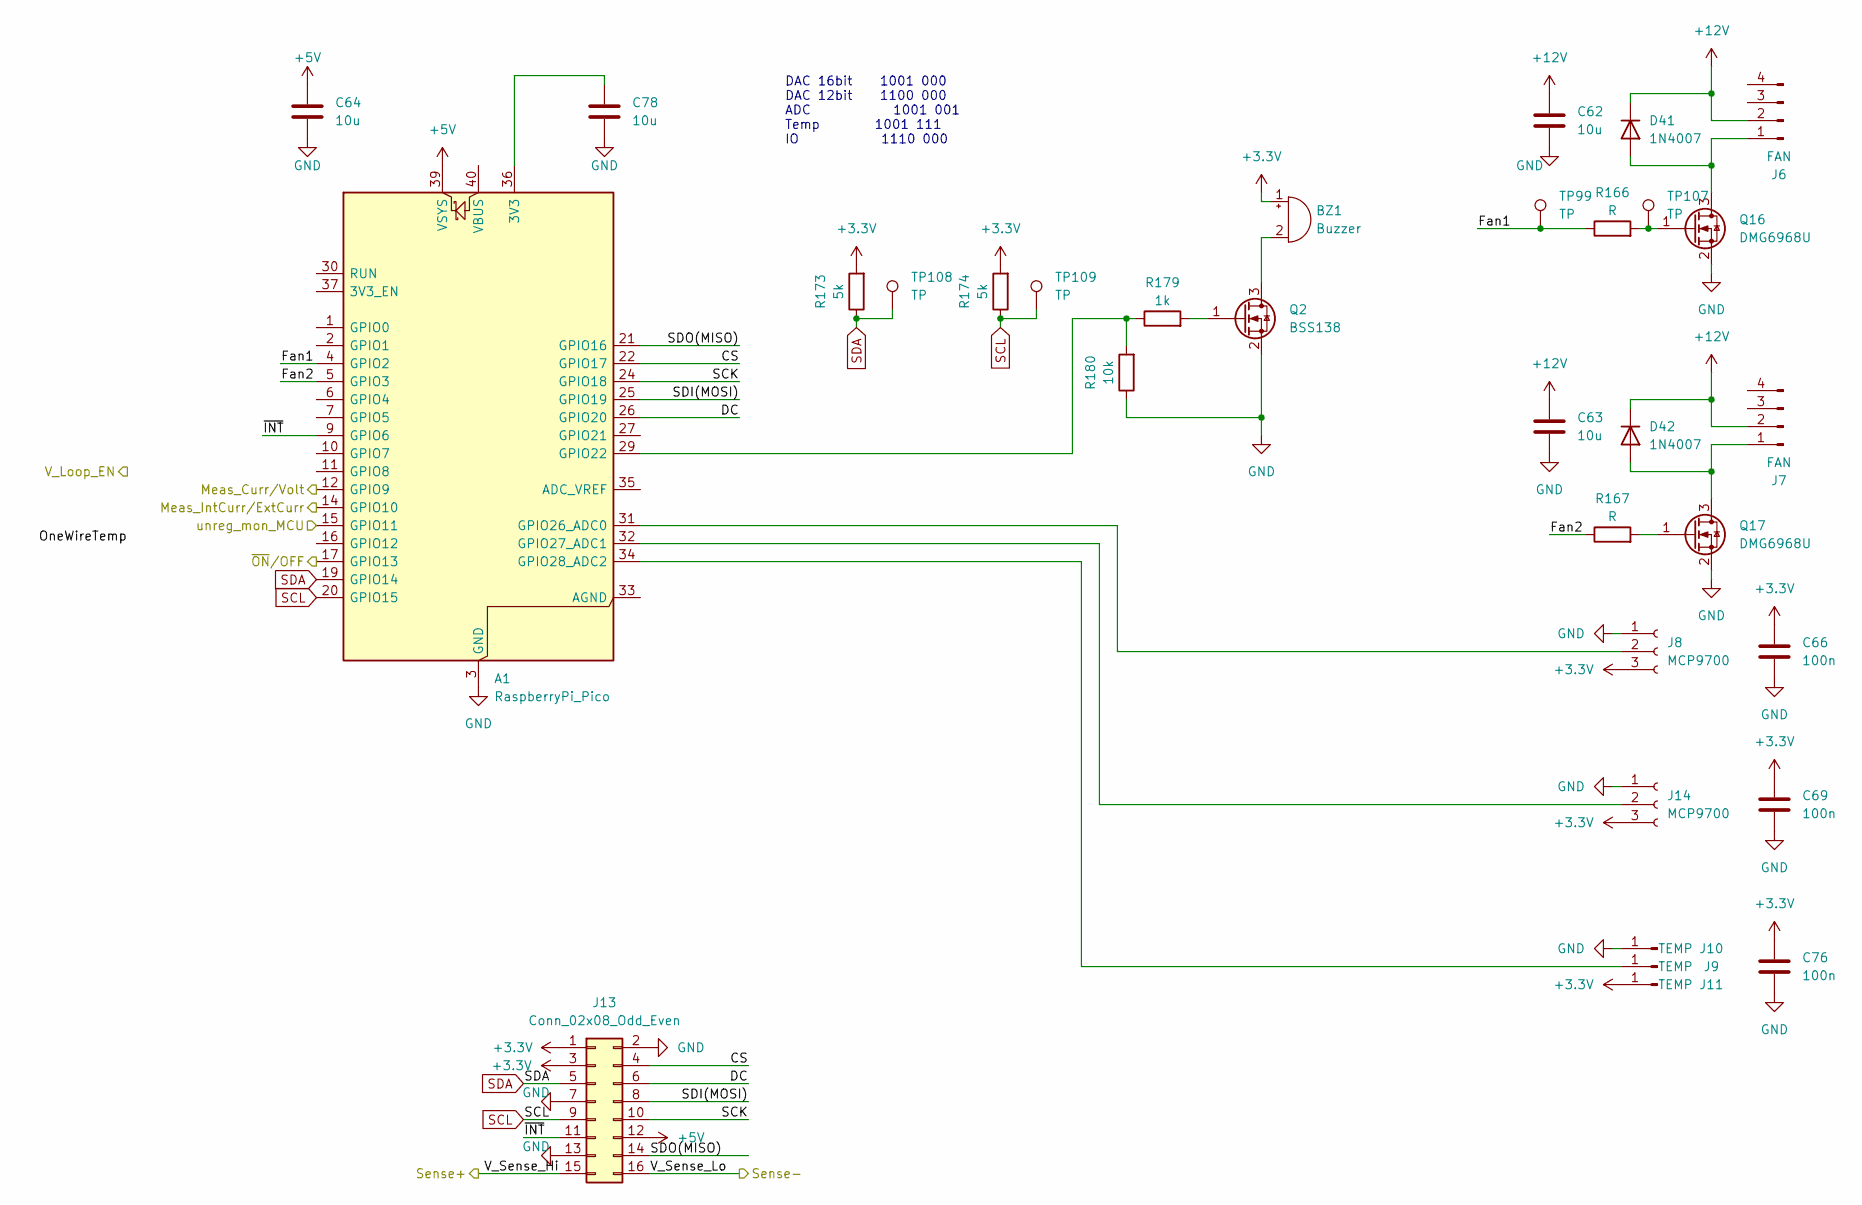
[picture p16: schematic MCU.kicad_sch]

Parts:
A1: RaspberryPi_Pico; RaspberryPi_Pico_Common_Unspecified
BZ1: Buzzer; Buzzer_12x9.5RM7.6
C62, C63: 10u; C_1206_3216Metric
C64, C78: 10u; C_0805_2012Metric
C66, C69, C76: 100n; C_0603_1608Metric
D41, D42: 1N4007; D_SOD-123F
J6, J7: FAN; FanPinHeader_1x04_P2.54mm_Vertical
J8, J14: MCP9700; JST_XH_B3B-XH-A_1x03_P2.50mm_Vertical
J9, J10, J11: TEMP; SolderWirePad_1x01_SMD_1.5x3mm
J13: Conn_02x08_Odd_Even; IDC-Header_2x08_P2.54mm_Vertical
Q2: BSS138; SOT-23-3
Q16, Q17: DMG6968U; SOT-23-3
R166, R167: R; R_0603_1608Metric
R173, R174: 5k; R_0603_1608Metric
R179: 1k; R_0603_1608Metric
R180: 10k; R_0603_1608Metric
TP99, TP107, TP108, TP109: TP; TestPoint_Pad_D1.0mm

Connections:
+3.3V: BZ1.1 (+), C66.1, C69.1, C76.1, J8.3, J11.1 (Pin_1_1), J13.1, J13.3, J14.3, R173.2, R174.2; also elsewhere on the board
+5V: A1.39 (VSYS), C64.1, J13.12; also elsewhere on the board
+12V: C62.1, C63.1, D41.1 (K), D42.1 (K), J6.2, J7.2; also elsewhere on the board
/DAC_ADC/Meas_IntCurr/ExtCurr: A1.14 (GPIO10); also elsewhere on the board
/MCU/CS: A1.22 (GPIO17), J13.4
/MCU/DC: A1.26 (GPIO20), J13.6
/MCU/Fan1: A1.4 (GPIO2), R166.1, TP99.1 (1_1)
/MCU/Fan2: A1.5 (GPIO3), R167.1
/MCU/Meas_Curr/Volt: A1.12 (GPIO9)
/MCU/OneWireTemp: A1.16 (GPIO12)
/MCU/SCK: A1.24 (GPIO18), J13.10
/MCU/SDI(MOSI): A1.25 (GPIO19), J13.8
/MCU/SDO(MISO): A1.21 (GPIO16), J13.14
/MCU/V_Loop_EN: A1.11 (GPIO8)
/MCU/V_Sense_Hi: J13.15; also elsewhere on the board
/MCU/V_Sense_Lo: J13.16; also elsewhere on the board
/MCU/unreg_mon_MCU: A1.15 (GPIO11); also elsewhere on the board
/MCU/~INT: A1.9 (GPIO6), J13.11
/MCU/~ON/OFF: A1.17 (GPIO13); also elsewhere on the board
GND: A1.3 (GND), A1.8 (GND), A1.13 (GND), A1.18 (GND), A1.23 (GND), A1.28 (GND), A1.38 (GND), C62.2, C63.2, C64.2, C66.2, C69.2, C76.2, C78.2, J8.1, J10.1 (Pin_1_1), J13.2, J13.7, J13.13, J14.1, Q2.2 (S), Q16.2 (S), Q17.2 (S), R180.1; also elsewhere on the board
unnamed: A1.36 (3V3), C78.1
unnamed: A1.29 (GPIO22), R179.1, R180.2
unnamed: A1.31 (GPIO26_ADC0), J8.2
unnamed: A1.32 (GPIO27_ADC1), J14.2
unnamed: A1.34 (GPIO28_ADC2), J9.1 (Pin_1_1)
unnamed: BZ1.2 (-), Q2.3 (D)
unnamed: D41.2 (A), J6.1, Q16.3 (D)
unnamed: D42.2 (A), J7.1, Q17.3 (D)
unnamed: Q2.1 (G), R179.2
unnamed: Q16.1 (G), R166.2, TP107.1 (1_1)
unnamed: Q17.1 (G), R167.2
SCL: A1.20 (GPIO15), J13.9, R174.1, TP109.1 (1_1); also elsewhere on the board
SDA: A1.19 (GPIO14), J13.5, R173.1, TP108.1 (1_1); also elsewhere on the board

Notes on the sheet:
DAC 16bit 1001 000 DAC 12bit 1100 000 ADC 1001 001 Temp 1001 111 IO 1110 000

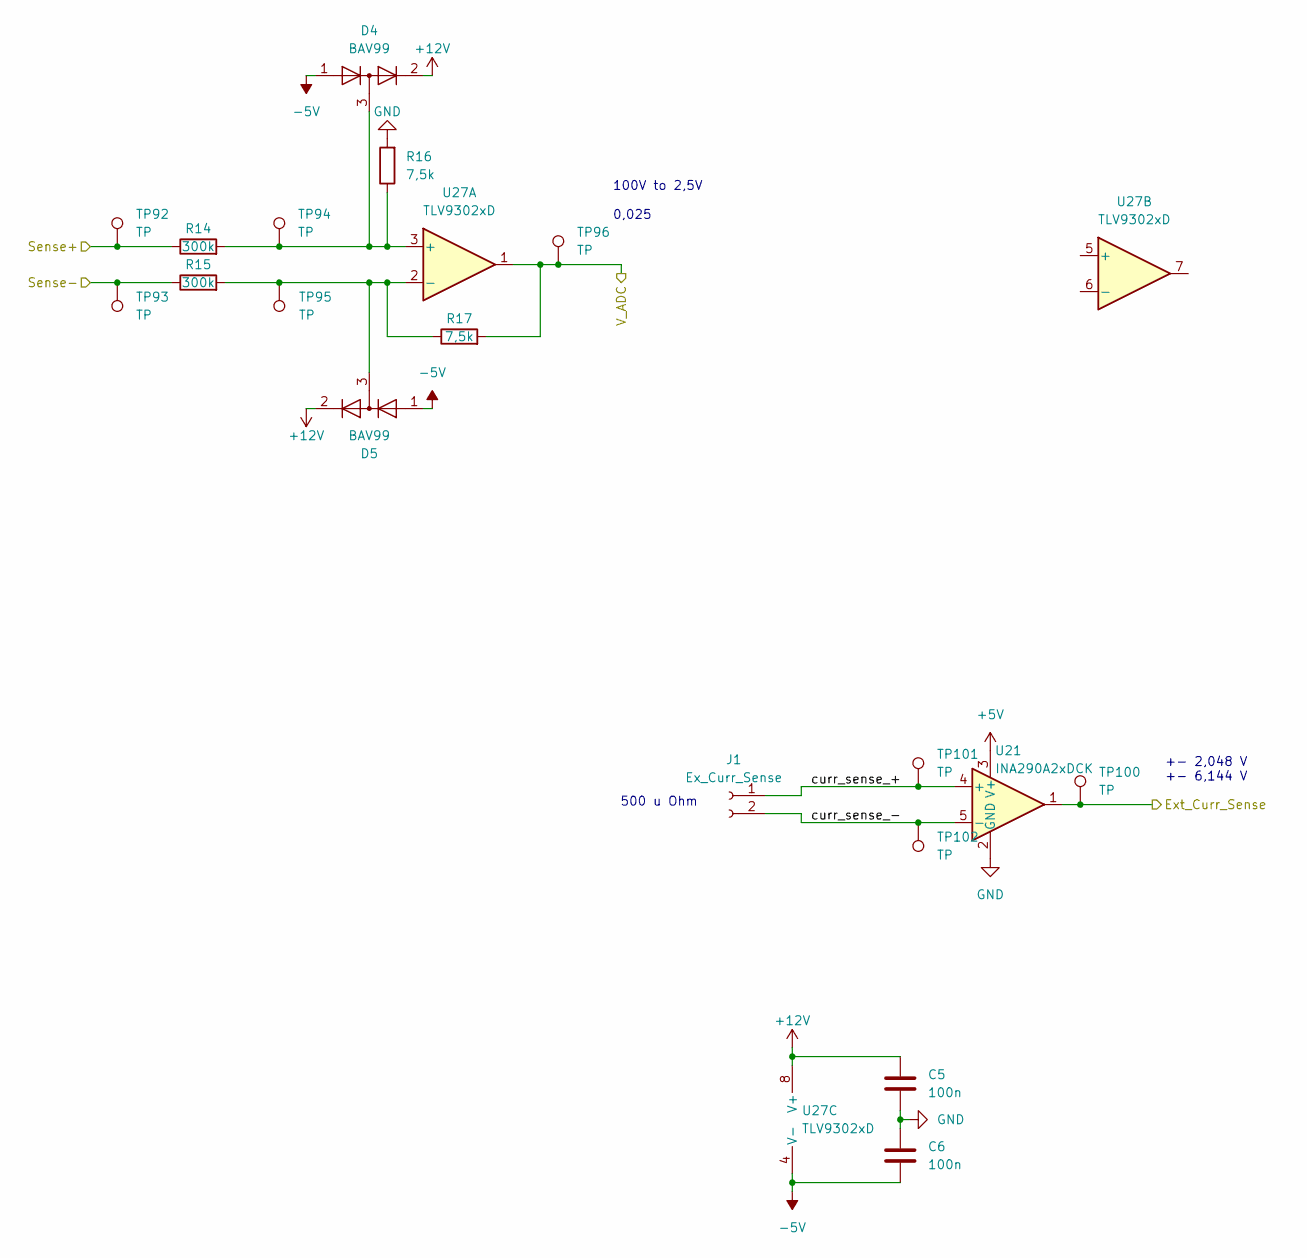
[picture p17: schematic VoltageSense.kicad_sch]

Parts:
C5, C6: 100n; C_0603_1608Metric
D4, D5: BAV99; SOT-23-3
J1: Ex_Curr_Sense; JST_XH_B2B-XH-A_1x02_P2.50mm_Vertical
R14, R15: 300k; R_0805_2012Metric
R16, R17: 7,5k; R_0805_2012Metric
TP92, TP93, TP94, TP95, TP96, TP100, TP101, TP102: TP; TestPoint_Pad_D1.0mm
U21: INA290A2xDCK; SOT-353_SC-70-5
U27: TLV9302xD; SOIC-8_3.9x4.9mm_P1.27mm

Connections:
+5V: U21.3 (V+); also elsewhere on the board
+12V: C5.1, D4.2 (A), D5.2 (A), U27.8 (V+); also elsewhere on the board
-5V: C6.2, D4.1 (K), D5.1 (K), U27.4 (V-); also elsewhere on the board
/DAC_ADC/Ext_Curr_Sense: TP100.1 (1_1), U21.1; also elsewhere on the board
/DAC_ADC/V_meas: R17.2, TP96.1 (1_1), U27.1; also elsewhere on the board
/MCU/V_Sense_Hi: R14.1, TP92.1 (1_1); also elsewhere on the board
/MCU/V_Sense_Lo: R15.1, TP93.1 (1_1); also elsewhere on the board
/VoltageSense/curr_sense_+: J1.1, TP101.1 (1_1), U21.4 (+)
/VoltageSense/curr_sense_-: J1.2, TP102.1 (1_1), U21.5 (-)
GND: C5.2, C6.1, R16.2, U21.2 (GND); also elsewhere on the board
unnamed: D4.3 (K), R14.2, R16.1, TP94.1 (1_1), U27.3 (+)
unnamed: D5.3 (K), R15.2, R17.1, TP95.1 (1_1), U27.2 (-)

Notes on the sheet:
500 u Ohm
100V to 2,5V 0,025
+- 2,048 V +- 6,144 V

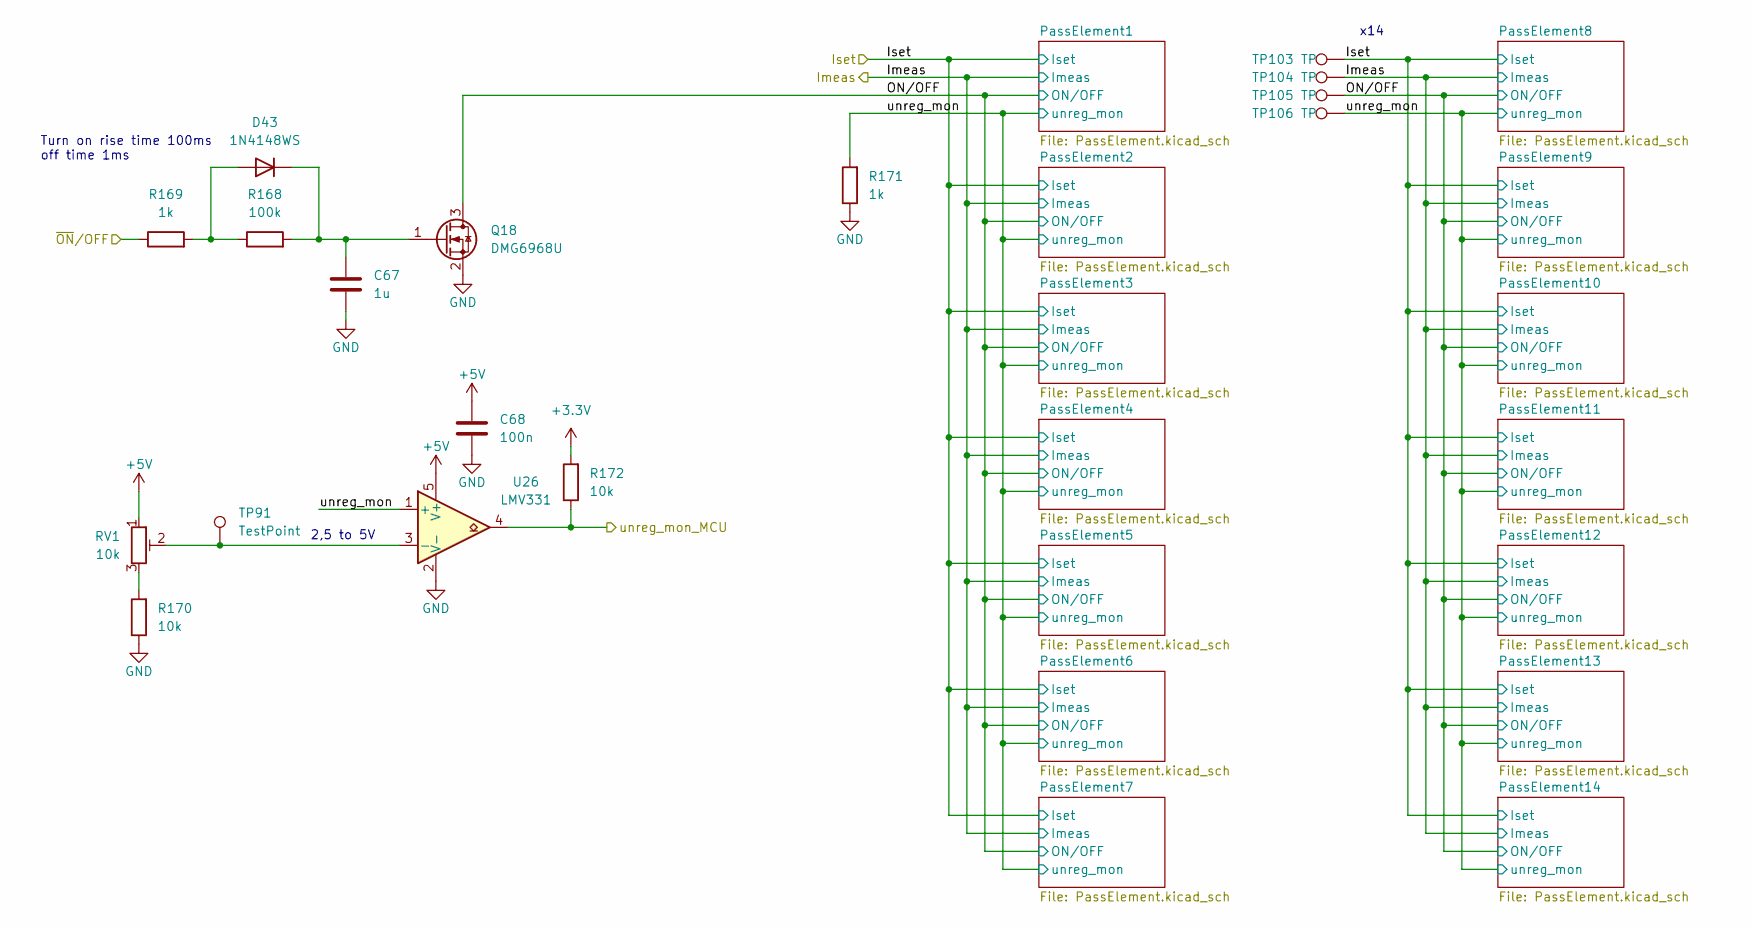
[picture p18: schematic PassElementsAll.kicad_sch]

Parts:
C67: 1u; C_0603_1608Metric
C68: 100n; C_0603_1608Metric
D43: 1N4148WS; D_SOD-323
Q18: DMG6968U; SOT-23-3
R168: 100k; R_0603_1608Metric
R169, R171: 1k; R_0603_1608Metric
R170, R172: 10k; R_0603_1608Metric
RV1: 10k; Potentiometer_Bourns_TC33X_Vertical
TP91: TestPoint; TestPoint_Pad_D1.0mm
TP103, TP104, TP105, TP106: TP; TestPoint_Keystone_5005-5009_Compact
U26: LMV331; SOT-23-5

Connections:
+3.3V: R172.2; also elsewhere on the board
+5V: C68.1, RV1.1, U26.5 (V+); also elsewhere on the board
/MCU/unreg_mon_MCU: R172.1, U26.4; also elsewhere on the board
/MCU/~ON/OFF: R169.1; also elsewhere on the board
/PassElementsAll/Imeas: TP104.1 (1_1); also elsewhere on the board
/PassElementsAll/Iset: TP103.1 (1_1); also elsewhere on the board
/PassElementsAll/ON/OFF: Q18.3 (D), TP105.1 (1_1); also elsewhere on the board
/PassElementsAll/unreg_mon: R171.2, TP106.1 (1_1), U26.1 (+); also elsewhere on the board
GND: C67.2, C68.2, Q18.2 (S), R170.1, R171.1, U26.2 (V-); also elsewhere on the board
unnamed: D43.2 (A), R168.1, R169.2
unnamed: C67.1, D43.1 (K), Q18.1 (G), R168.2
unnamed: R170.2, RV1.3
unnamed: RV1.2, TP91.1 (1_1), U26.3 (-)

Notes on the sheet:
x14
Turn on rise time 100ms off time 1ms
2,5 to 5V

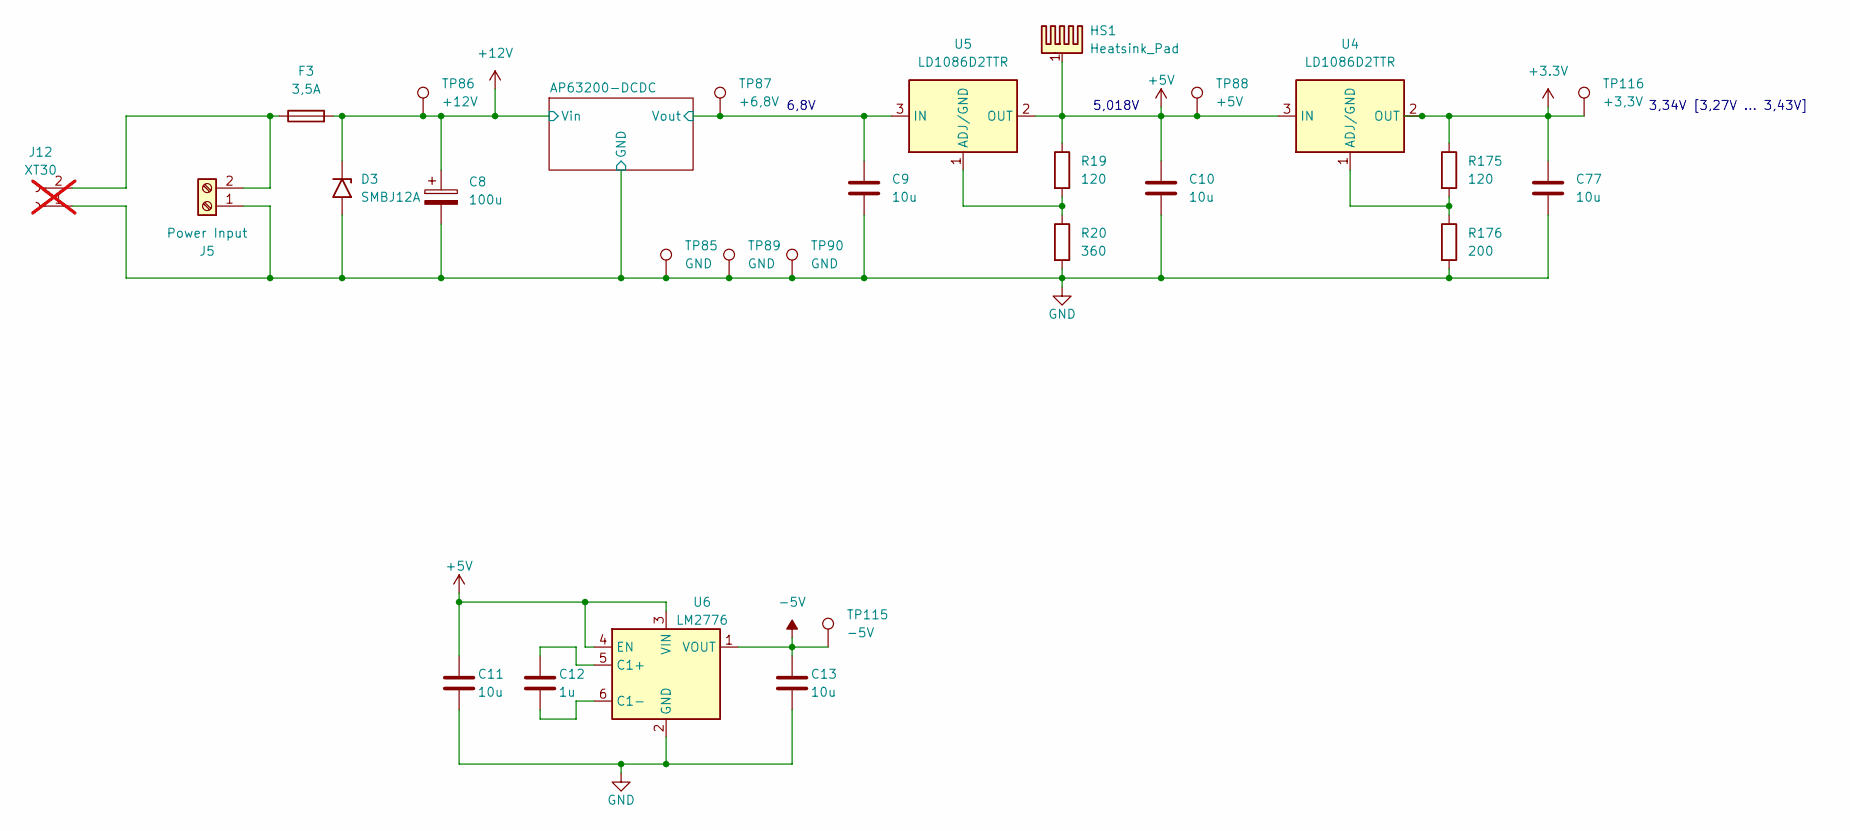
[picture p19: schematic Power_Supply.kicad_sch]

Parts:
C8: 100u; CP_Elec_8x10.5
C9, C10, C11, C13, C77: 10u; C_0805_2012Metric
C12: 1u; C_0805_2012Metric
D3: SMBJ12A; D_SMB
F3: 3,5A; Fuse_1206_3216Metric
HS1: Heatsink_Pad; Heatsink_AAVID_573300D00010G_TO-263
J5: Power Input; PhoenixContact_MC_1,5_2-G-3.81_1x02_P3.81mm_Horizontal
J12: XT30; AMASS_XT30PW-M_1x02_P2.50mm_Horizontal; not fitted
R19, R175: 120; R_0603_1608Metric
R20: 360; R_0603_1608Metric
R176: 200; R_0603_1608Metric
TP85, TP89, TP90: GND; TestPoint_Keystone_5005-5009_Compact
TP86: +12V; TestPoint_Keystone_5005-5009_Compact
TP87: +6,8V; TestPoint_Keystone_5005-5009_Compact
TP88: +5V; TestPoint_Keystone_5005-5009_Compact
TP115: -5V; TestPoint_Keystone_5005-5009_Compact
TP116: +3,3V; TestPoint_Keystone_5005-5009_Compact
U4, U5: LD1086D2TTR; TO-263-2
U6: LM2776; SOT-23-6

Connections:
+3.3V: C77.1, R175.1, TP116.1 (1_1), U4.2 (OUT); also elsewhere on the board
+5V: C10.1, C11.1, HS1.1, R19.1, TP88.1 (1_1), U4.3 (IN), U5.2 (OUT), U6.3 (VIN), U6.4 (EN); also elsewhere on the board
+12V: C8.1, D3.1 (A1), F3.2, TP86.1 (1_1); also elsewhere on the board
-5V: C13.1, TP115.1 (1_1), U6.1 (VOUT); also elsewhere on the board
/Power Supply/AP63200-DCDC/Vout: C9.1, TP87.1 (1_1), U5.3 (IN); also elsewhere on the board
GND: C8.2, C9.2, C10.2, C11.2, C13.2, C77.2, D3.2 (A2), J5.1, J12.1, R20.2, R176.2, TP85.1 (1_1), TP89.1 (1_1), TP90.1 (1_1), U6.2 (GND); also elsewhere on the board
unnamed: F3.1, J5.2, J12.2
unnamed: R175.2, R176.1, U4.1 (ADJ/GND)
unnamed: R19.2, R20.1, U5.1 (ADJ/GND)
unnamed: C12.1, U6.5 (C1+)
unnamed: C12.2, U6.6 (C1-)

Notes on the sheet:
6,8V
3,34V [3,27V ... 3,43V]
5,018V

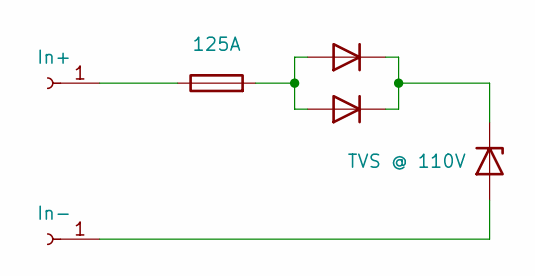
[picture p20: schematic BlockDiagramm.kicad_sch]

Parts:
D7, D8: D
D9: TVS @ 110V
F2: 125A
J3: In+
J4: In-

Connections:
unnamed: D7.1 (K), D8.1 (K), D9.1 (K)
unnamed: D7.2 (A), D8.2 (A), F2.2
unnamed: D9.2 (A), J4.1
unnamed: F2.1, J3.1

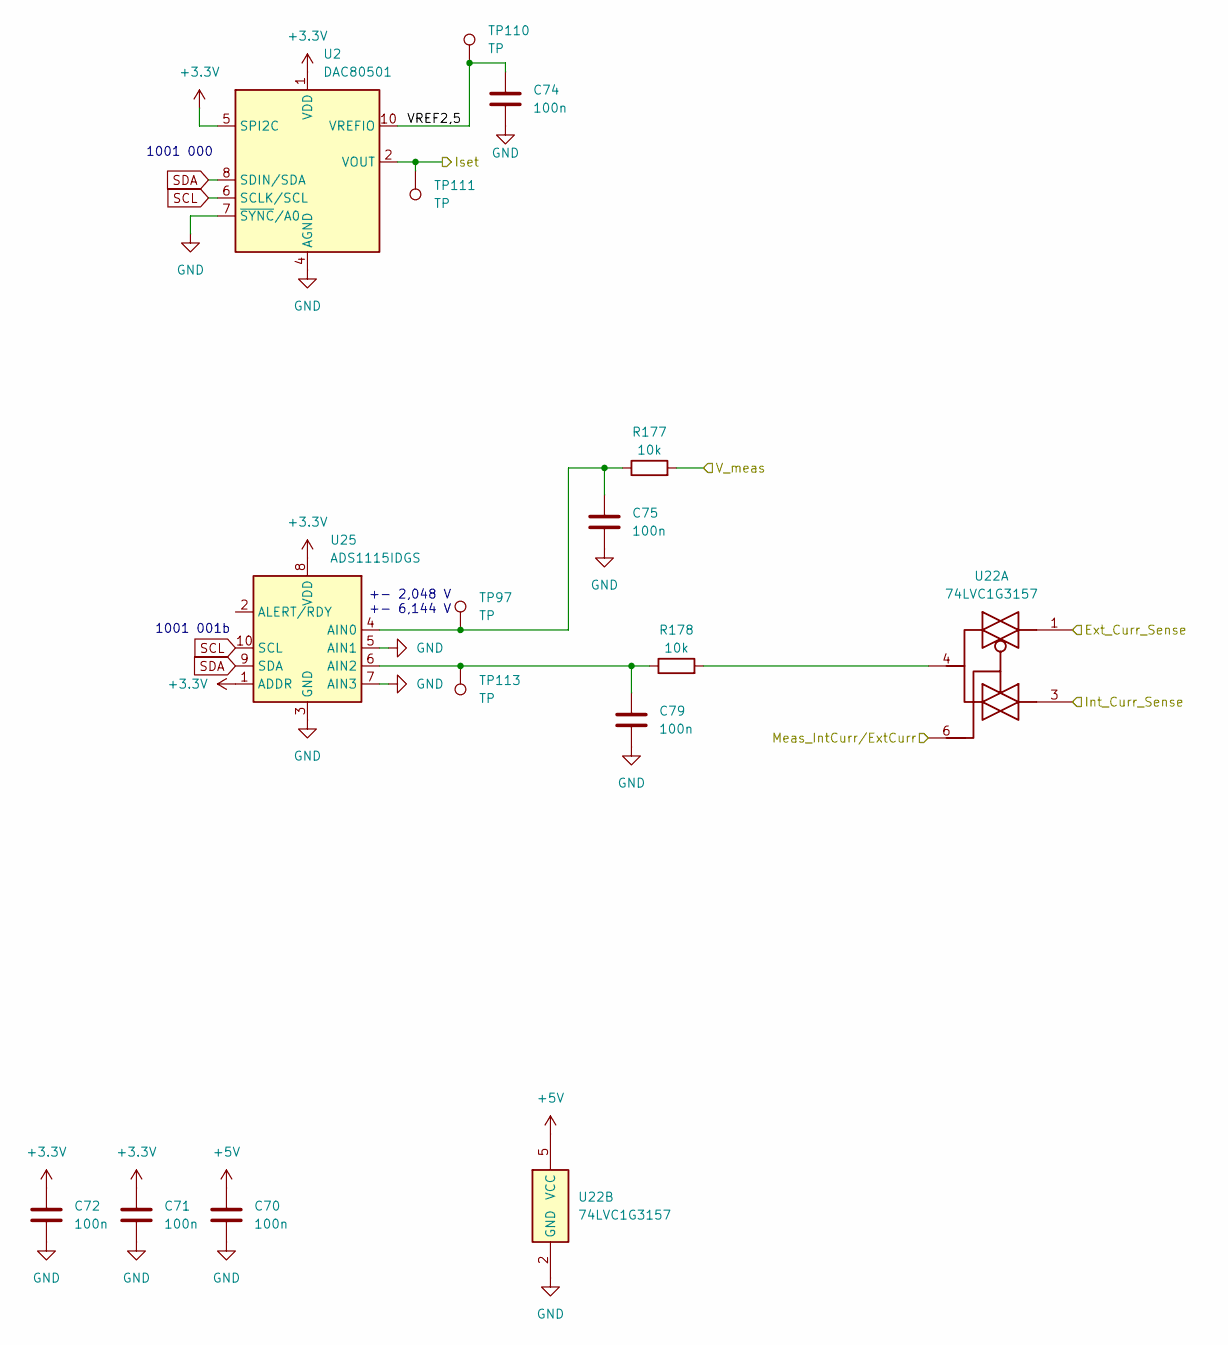
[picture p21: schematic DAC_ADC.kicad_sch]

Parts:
C70, C71, C72, C74, C75, C79: 100n; C_0603_1608Metric
R177, R178: 10k; R_0603_1608Metric
TP97, TP110, TP111, TP113: TP; TestPoint_Pad_D1.0mm
U2: DAC80501; VSSOP-10_3x3mm_P0.5mm
U22: 74LVC1G3157; SOT-363_SC-70-6
U25: ADS1115IDGS; TSSOP-10_3x3mm_P0.5mm

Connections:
+3.3V: C71.1, C72.1, U2.1 (VDD), U2.5 (SPI2C), U25.1 (ADDR), U25.8 (VDD); also elsewhere on the board
+5V: C70.1, U22.5 (VCC); also elsewhere on the board
/DAC_ADC/Ext_Curr_Sense: U22.1; also elsewhere on the board
/DAC_ADC/Meas_IntCurr/ExtCurr: U22.6; also elsewhere on the board
/DAC_ADC/VREF2,5: C74.1, TP110.1 (1_1), U2.10 (VREFIO)
/DAC_ADC/V_meas: R177.2; also elsewhere on the board
/PassElementsAll/Imeas: U22.3; also elsewhere on the board
/PassElementsAll/Iset: TP111.1 (1_1), U2.2 (VOUT); also elsewhere on the board
GND: C70.2, C71.2, C72.2, C74.2, C75.2, C79.2, U2.4 (AGND), U2.7 (~SYNC/A0), U22.2 (GND), U25.3 (GND), U25.5 (AIN1), U25.7 (AIN3); also elsewhere on the board
unnamed: R178.2, U22.4
unnamed: C75.1, R177.1, TP97.1 (1_1), U25.4 (AIN0)
unnamed: C79.1, R178.1, TP113.1 (1_1), U25.6 (AIN2)
SCL: U2.6 (SCLK/SCL), U25.10 (SCL); also elsewhere on the board
SDA: U2.8 (SDIN/SDA), U25.9 (SDA); also elsewhere on the board

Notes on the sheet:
1001 001b
1001 000
+- 2,048 V +- 6,144 V

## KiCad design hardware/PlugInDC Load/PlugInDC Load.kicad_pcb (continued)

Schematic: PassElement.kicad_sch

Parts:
C1: 100n; C_0603_1608Metric; not fitted
C2: 10n; C_0603_1608Metric
C3: 100n; C_0603_1608Metric
D1, D2: 1N4148WX; D_SOD-323
F1: 10A; Fuse_1206_3216Metric
H1, H2: M3; MountingHole_3.2mm_M3_DIN965_Pad
Q1: MJH6284; MR30
R2, R3, R4, R10, R11: 1k; R_0603_1608Metric
R5: 500; R_0603_1608Metric; not fitted
R6: 10k; R_0603_1608Metric
R7, R9: 62k; R_0603_1608Metric
R8: 150; R_1206_3216Metric
R12: 0,005; R_2512_6332Metric
TP1: Int-; TestPoint_Pad_D1.0mm
TP2: CurrO; TestPoint_Pad_D1.0mm
TP3: IntO; TestPoint_Pad_D1.0mm
TP4: B; TestPoint_Pad_D1.0mm
TP5: CrrH; TestPoint_Pad_D1.0mm
TP6: CurrL; TestPoint_Pad_D1.0mm
U3: TLV9152; SOT-23-8

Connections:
+5V: C3.2, U3.8 (V+); also elsewhere on the board
/PassElementsAll/Imeas: R4.1; also elsewhere on the board
/PassElementsAll/Iset: R2.1; also elsewhere on the board
/PassElementsAll/ON/OFF: D2.1 (K); also elsewhere on the board
/PassElementsAll/PassElement2/Emitter: F1.1, Q1.3 (E)
/PassElementsAll/PassElement2/R_to_F: F1.2, R10.2, R12.1, TP5.1 (1_1)
/PassElementsAll/unreg_mon: D1.1 (K); also elsewhere on the board
GND: C3.1, R6.1, R9.2, U3.4 (V-); also elsewhere on the board
GNDPWR: H1.1 (1_1), R11.2, R12.2, TP6.1 (1_1); also elsewhere on the board
unnamed: C1.2, R5.1
unnamed: C2.2, D1.2 (A), R5.2, R6.2, R8.1, TP3.1 (1_1), U3.1
unnamed: D2.2 (A), Q1.1 (B), R8.2, TP4.1 (1_1)
unnamed: R3.2, R4.2, R7.1, TP2.1 (1_1), U3.7
unnamed: R2.2, U3.3 (+)
unnamed: C1.1, C2.1, R3.1, TP1.1 (1_1), U3.2 (-)
unnamed: R9.1, R10.1, U3.5 (+)
unnamed: R7.2, R11.1, U3.6 (-)
VBUS: H2.1 (1_1), Q1.2 (C); also elsewhere on the board

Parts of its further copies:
C23, C26, C29, C32, C35, C38, C41, C44, C47, C50, C53, C56, C59: 100n; C_0603_1608Metric; not fitted
C24, C27, C30, C33, C36, C39, C42, C45, C48, C51, C54, C57, C60: 10n; C_0603_1608Metric
C25, C28, C31, C34, C37, C40, C43, C46, C49, C52, C55, C58, C61: 100n; C_0603_1608Metric
D15, D16, D17, D18, D19, D20, D21, D22, D23, D24, D25, D26, D27, D28, D29, D30, D31, D32, D33, D34, D35, D36, D37, D38, D39, D40: 1N4148WX; D_SOD-323
F4, F5, F6, F7, F8, F9, F10, F11, F12, F13, F14, F15, F16: 10A; Fuse_1206_3216Metric
H5, H6, H7, H8, H9, H10, H11, H12, H13, H14, H15, H16, H17, H18, H19, H20, H21, H22, H23, H24, H25, H26, H27, H28, H29, H30: M3; MountingHole_3.2mm_M3_DIN965_Pad
Q3, Q4, Q5, Q6, Q7, Q8, Q9, Q10, Q11, Q12, Q13, Q14, Q15: MJH6284; MR30
R23, R24, R25, R31, R32, R34, R35, R36, R42, R43, R45, R46, R47, R53, R54, R56, R57, R58, R64, R65, R67, R68, R69, R75, R76, R78, R79, R80, R86, R87, R89, R90, R91, R97, R98, R100, R101, R102, R108, R109, R111, R112, R113, R119, R120, R122, R123, R124, R130, R131, R133, R134, R135, R141, R142, R144, R145, R146, R152, R153, R155, R156, R157, R163, R164: 1k; R_0603_1608Metric
R26, R37, R48, R59, R70, R81, R92, R103, R114, R125, R136, R147, R158: 500; R_0603_1608Metric; not fitted
R27, R38, R49, R60, R71, R82, R93, R104, R115, R126, R137, R148, R159: 10k; R_0603_1608Metric
R28, R30, R39, R41, R50, R52, R61, R63, R72, R74, R83, R85, R94, R96, R105, R107, R116, R118, R127, R129, R138, R140, R149, R151, R160, R162: 62k; R_0603_1608Metric
R29, R40, R51, R62, R73, R84, R95, R106, R117, R128, R139, R150, R161: 150; R_1206_3216Metric
R33, R44, R55, R66, R77, R88, R99, R110, R121, R132, R143, R154, R165: 0,005; R_2512_6332Metric
TP7, TP13, TP19, TP25, TP31, TP37, TP43, TP49, TP55, TP61, TP67, TP73, TP79: Int-; TestPoint_Pad_D1.0mm
TP8, TP14, TP20, TP26, TP32, TP38, TP44, TP50, TP56, TP62, TP68, TP74, TP80: CurrO; TestPoint_Pad_D1.0mm
TP9, TP15, TP21, TP27, TP33, TP39, TP45, TP51, TP57, TP63, TP69, TP75, TP81: IntO; TestPoint_Pad_D1.0mm
TP10, TP16, TP22, TP28, TP34, TP40, TP46, TP52, TP58, TP64, TP70, TP76, TP82: B; TestPoint_Pad_D1.0mm
TP11, TP17, TP23, TP29, TP35, TP41, TP47, TP53, TP59, TP65, TP71, TP77, TP83: CrrH; TestPoint_Pad_D1.0mm
TP12, TP18, TP24, TP30, TP36, TP42, TP48, TP54, TP60, TP66, TP72, TP78, TP84: CurrL; TestPoint_Pad_D1.0mm
U8, U9, U10, U11, U12, U13, U14, U15, U16, U17, U18, U19, U20: TLV9152; SOT-23-8

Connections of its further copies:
+5V: C25.2, C28.2, C31.2, C34.2, C37.2, C40.2, C43.2, C46.2, C49.2, C52.2, C55.2, C58.2, C61.2, U8.8 (V+), U9.8 (V+), U10.8 (V+), U11.8 (V+), U12.8 (V+), U13.8 (V+), U14.8 (V+), U15.8 (V+), U16.8 (V+), U17.8 (V+), U18.8 (V+), U19.8 (V+), U20.8 (V+); also elsewhere on the board
/PassElementsAll/Imeas: R25.1, R36.1, R47.1, R58.1, R69.1, R80.1, R91.1, R102.1, R113.1, R124.1, R135.1, R146.1, R157.1; also elsewhere on the board
/PassElementsAll/Iset: R23.1, R34.1, R45.1, R56.1, R67.1, R78.1, R89.1, R100.1, R111.1, R122.1, R133.1, R144.1, R155.1; also elsewhere on the board
/PassElementsAll/ON/OFF: D16.1 (K), D18.1 (K), D20.1 (K), D22.1 (K), D24.1 (K), D26.1 (K), D28.1 (K), D30.1 (K), D32.1 (K), D34.1 (K), D36.1 (K), D38.1 (K), D40.1 (K); also elsewhere on the board
/PassElementsAll/PassElement1/Emitter: F4.1, Q3.3 (E)
/PassElementsAll/PassElement1/R_to_F: F4.2, R31.2, R33.1, TP11.1 (1_1)
/PassElementsAll/PassElement3/Emitter: F5.1, Q4.3 (E)
/PassElementsAll/PassElement3/R_to_F: F5.2, R42.2, R44.1, TP17.1 (1_1)
/PassElementsAll/PassElement4/Emitter: F6.1, Q5.3 (E)
/PassElementsAll/PassElement4/R_to_F: F6.2, R53.2, R55.1, TP23.1 (1_1)
/PassElementsAll/PassElement5/Emitter: F7.1, Q6.3 (E)
/PassElementsAll/PassElement5/R_to_F: F7.2, R64.2, R66.1, TP29.1 (1_1)
/PassElementsAll/PassElement6/Emitter: F8.1, Q7.3 (E)
/PassElementsAll/PassElement6/R_to_F: F8.2, R75.2, R77.1, TP35.1 (1_1)
/PassElementsAll/PassElement7/Emitter: F9.1, Q8.3 (E)
/PassElementsAll/PassElement7/R_to_F: F9.2, R86.2, R88.1, TP41.1 (1_1)
/PassElementsAll/PassElement8/Emitter: F10.1, Q9.3 (E)
/PassElementsAll/PassElement8/R_to_F: F10.2, R97.2, R99.1, TP47.1 (1_1)
/PassElementsAll/PassElement9/Emitter: F11.1, Q10.3 (E)
/PassElementsAll/PassElement9/R_to_F: F11.2, R108.2, R110.1, TP53.1 (1_1)
/PassElementsAll/PassElement10/Emitter: F12.1, Q11.3 (E)
/PassElementsAll/PassElement10/R_to_F: F12.2, R119.2, R121.1, TP59.1 (1_1)
/PassElementsAll/PassElement11/Emitter: F13.1, Q12.3 (E)
/PassElementsAll/PassElement11/R_to_F: F13.2, R130.2, R132.1, TP65.1 (1_1)
/PassElementsAll/PassElement12/Emitter: F14.1, Q13.3 (E)
/PassElementsAll/PassElement12/R_to_F: F14.2, R141.2, R143.1, TP71.1 (1_1)
/PassElementsAll/PassElement13/Emitter: F16.1, Q15.3 (E)
/PassElementsAll/PassElement13/R_to_F: F16.2, R163.2, R165.1, TP83.1 (1_1)
/PassElementsAll/PassElement14/Emitter: F15.1, Q14.3 (E)
/PassElementsAll/PassElement14/R_to_F: F15.2, R152.2, R154.1, TP77.1 (1_1)
/PassElementsAll/unreg_mon: D15.1 (K), D17.1 (K), D19.1 (K), D21.1 (K), D23.1 (K), D25.1 (K), D27.1 (K), D29.1 (K), D31.1 (K), D33.1 (K), D35.1 (K), D37.1 (K), D39.1 (K); also elsewhere on the board
GND: C25.1, C28.1, C31.1, C34.1, C37.1, C40.1, C43.1, C46.1, C49.1, C52.1, C55.1, C58.1, C61.1, R27.1, R30.2, R38.1, R41.2, R49.1, R52.2, R60.1, R63.2, R71.1, R74.2, R82.1, R85.2, R93.1, R96.2, R104.1, R107.2, R115.1, R118.2, R126.1, R129.2, R137.1, R140.2, R148.1, R151.2, R159.1, R162.2, U8.4 (V-), U9.4 (V-), U10.4 (V-), U11.4 (V-), U12.4 (V-), U13.4 (V-), U14.4 (V-), U15.4 (V-), U16.4 (V-), U17.4 (V-), U18.4 (V-), U19.4 (V-), U20.4 (V-); also elsewhere on the board
GNDPWR: H5.1 (1_1), H7.1 (1_1), H9.1 (1_1), H11.1 (1_1), H13.1 (1_1), H15.1 (1_1), H17.1 (1_1), H19.1 (1_1), H21.1 (1_1), H23.1 (1_1), H25.1 (1_1), H27.1 (1_1), H29.1 (1_1), R32.2, R33.2, R43.2, R44.2, R54.2, R55.2, R65.2, R66.2, R76.2, R77.2, R87.2, R88.2, R98.2, R99.2, R109.2, R110.2, R120.2, R121.2, R131.2, R132.2, R142.2, R143.2, R153.2, R154.2, R164.2, R165.2, TP12.1 (1_1), TP18.1 (1_1), TP24.1 (1_1), TP30.1 (1_1), TP36.1 (1_1), TP42.1 (1_1), TP48.1 (1_1), TP54.1 (1_1), TP60.1 (1_1), TP66.1 (1_1), TP72.1 (1_1), TP78.1 (1_1), TP84.1 (1_1); also elsewhere on the board
unnamed: C23.2, R26.1
unnamed: C26.2, R37.1
unnamed: C29.2, R48.1
unnamed: C32.2, R59.1
unnamed: C35.2, R70.1
unnamed: C38.2, R81.1
unnamed: C41.2, R92.1
unnamed: C44.2, R103.1
unnamed: C47.2, R114.1
unnamed: C50.2, R125.1
unnamed: C53.2, R136.1
unnamed: C56.2, R147.1
unnamed: C59.2, R158.1
unnamed: C24.2, D15.2 (A), R26.2, R27.2, R29.1, TP9.1 (1_1), U8.1
unnamed: D16.2 (A), Q3.1 (B), R29.2, TP10.1 (1_1)
unnamed: C27.2, D17.2 (A), R37.2, R38.2, R40.1, TP15.1 (1_1), U9.1
unnamed: D18.2 (A), Q4.1 (B), R40.2, TP16.1 (1_1)
unnamed: C30.2, D19.2 (A), R48.2, R49.2, R51.1, TP21.1 (1_1), U10.1
unnamed: D20.2 (A), Q5.1 (B), R51.2, TP22.1 (1_1)
unnamed: C33.2, D21.2 (A), R59.2, R60.2, R62.1, TP27.1 (1_1), U11.1
unnamed: D22.2 (A), Q6.1 (B), R62.2, TP28.1 (1_1)
unnamed: C36.2, D23.2 (A), R70.2, R71.2, R73.1, TP33.1 (1_1), U12.1
unnamed: D24.2 (A), Q7.1 (B), R73.2, TP34.1 (1_1)
unnamed: C39.2, D25.2 (A), R81.2, R82.2, R84.1, TP39.1 (1_1), U13.1
unnamed: D26.2 (A), Q8.1 (B), R84.2, TP40.1 (1_1)
unnamed: C42.2, D27.2 (A), R92.2, R93.2, R95.1, TP45.1 (1_1), U14.1
unnamed: D28.2 (A), Q9.1 (B), R95.2, TP46.1 (1_1)
unnamed: C45.2, D29.2 (A), R103.2, R104.2, R106.1, TP51.1 (1_1), U15.1
unnamed: D30.2 (A), Q10.1 (B), R106.2, TP52.1 (1_1)
unnamed: C48.2, D31.2 (A), R114.2, R115.2, R117.1, TP57.1 (1_1), U16.1
unnamed: D32.2 (A), Q11.1 (B), R117.2, TP58.1 (1_1)
unnamed: C51.2, D33.2 (A), R125.2, R126.2, R128.1, TP63.1 (1_1), U17.1
unnamed: D34.2 (A), Q12.1 (B), R128.2, TP64.1 (1_1)
unnamed: C54.2, D35.2 (A), R136.2, R137.2, R139.1, TP69.1 (1_1), U18.1
unnamed: D36.2 (A), Q13.1 (B), R139.2, TP70.1 (1_1)
unnamed: C57.2, D37.2 (A), R147.2, R148.2, R150.1, TP75.1 (1_1), U19.1
unnamed: D38.2 (A), Q14.1 (B), R150.2, TP76.1 (1_1)
unnamed: C60.2, D39.2 (A), R158.2, R159.2, R161.1, TP81.1 (1_1), U20.1
unnamed: D40.2 (A), Q15.1 (B), R161.2, TP82.1 (1_1)
unnamed: R24.2, R25.2, R28.1, TP8.1 (1_1), U8.7
unnamed: R35.2, R36.2, R39.1, TP14.1 (1_1), U9.7
unnamed: R46.2, R47.2, R50.1, TP20.1 (1_1), U10.7
unnamed: R57.2, R58.2, R61.1, TP26.1 (1_1), U11.7
unnamed: R68.2, R69.2, R72.1, TP32.1 (1_1), U12.7
unnamed: R79.2, R80.2, R83.1, TP38.1 (1_1), U13.7
unnamed: R90.2, R91.2, R94.1, TP44.1 (1_1), U14.7
unnamed: R101.2, R102.2, R105.1, TP50.1 (1_1), U15.7
unnamed: R112.2, R113.2, R116.1, TP56.1 (1_1), U16.7
unnamed: R123.2, R124.2, R127.1, TP62.1 (1_1), U17.7
unnamed: R134.2, R135.2, R138.1, TP68.1 (1_1), U18.7
unnamed: R145.2, R146.2, R149.1, TP74.1 (1_1), U19.7
unnamed: R156.2, R157.2, R160.1, TP80.1 (1_1), U20.7
unnamed: R23.2, U8.3 (+)
unnamed: C23.1, C24.1, R24.1, TP7.1 (1_1), U8.2 (-)
unnamed: R30.1, R31.1, U8.5 (+)
unnamed: R28.2, R32.1, U8.6 (-)
unnamed: R34.2, U9.3 (+)
unnamed: C26.1, C27.1, R35.1, TP13.1 (1_1), U9.2 (-)
unnamed: R41.1, R42.1, U9.5 (+)
unnamed: R39.2, R43.1, U9.6 (-)
unnamed: R45.2, U10.3 (+)
unnamed: C29.1, C30.1, R46.1, TP19.1 (1_1), U10.2 (-)
unnamed: R52.1, R53.1, U10.5 (+)
unnamed: R50.2, R54.1, U10.6 (-)
unnamed: R56.2, U11.3 (+)
unnamed: C32.1, C33.1, R57.1, TP25.1 (1_1), U11.2 (-)
unnamed: R63.1, R64.1, U11.5 (+)
unnamed: R61.2, R65.1, U11.6 (-)
unnamed: R67.2, U12.3 (+)
unnamed: C35.1, C36.1, R68.1, TP31.1 (1_1), U12.2 (-)
unnamed: R74.1, R75.1, U12.5 (+)
unnamed: R72.2, R76.1, U12.6 (-)
unnamed: R78.2, U13.3 (+)
unnamed: C38.1, C39.1, R79.1, TP37.1 (1_1), U13.2 (-)
unnamed: R85.1, R86.1, U13.5 (+)
unnamed: R83.2, R87.1, U13.6 (-)
unnamed: R89.2, U14.3 (+)
unnamed: C41.1, C42.1, R90.1, TP43.1 (1_1), U14.2 (-)
unnamed: R96.1, R97.1, U14.5 (+)
unnamed: R94.2, R98.1, U14.6 (-)
unnamed: R100.2, U15.3 (+)
unnamed: C44.1, C45.1, R101.1, TP49.1 (1_1), U15.2 (-)
unnamed: R107.1, R108.1, U15.5 (+)
unnamed: R105.2, R109.1, U15.6 (-)
unnamed: R111.2, U16.3 (+)
unnamed: C47.1, C48.1, R112.1, TP55.1 (1_1), U16.2 (-)
unnamed: R118.1, R119.1, U16.5 (+)
unnamed: R116.2, R120.1, U16.6 (-)
unnamed: R122.2, U17.3 (+)
unnamed: C50.1, C51.1, R123.1, TP61.1 (1_1), U17.2 (-)
unnamed: R129.1, R130.1, U17.5 (+)
unnamed: R127.2, R131.1, U17.6 (-)
unnamed: R133.2, U18.3 (+)
unnamed: C53.1, C54.1, R134.1, TP67.1 (1_1), U18.2 (-)
unnamed: R140.1, R141.1, U18.5 (+)
unnamed: R138.2, R142.1, U18.6 (-)
unnamed: R144.2, U19.3 (+)
unnamed: C56.1, C57.1, R145.1, TP73.1 (1_1), U19.2 (-)
unnamed: R151.1, R152.1, U19.5 (+)
unnamed: R149.2, R153.1, U19.6 (-)
unnamed: R155.2, U20.3 (+)
unnamed: C59.1, C60.1, R156.1, TP79.1 (1_1), U20.2 (-)
unnamed: R162.1, R163.1, U20.5 (+)
unnamed: R160.2, R164.1, U20.6 (-)
VBUS: H6.1 (1_1), H8.1 (1_1), H10.1 (1_1), H12.1 (1_1), H14.1 (1_1), H16.1 (1_1), H18.1 (1_1), H20.1 (1_1), H22.1 (1_1), H24.1 (1_1), H26.1 (1_1), H28.1 (1_1), H30.1 (1_1), Q3.2 (C), Q4.2 (C), Q5.2 (C), Q6.2 (C), Q7.2 (C), Q8.2 (C), Q9.2 (C), Q10.2 (C), Q11.2 (C), Q12.2 (C), Q13.2 (C), Q14.2 (C), Q15.2 (C); also elsewhere on the board

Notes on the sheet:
Supply: max 5V ~25mA
0 - 2,5V 0 - 8,0645A
2,5V
G = 62

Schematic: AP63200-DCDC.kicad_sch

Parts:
C14: 10u; C_1206_3216Metric
C15, C16, C22: 100n; C_0603_1608Metric
C17: 100p; C_0603_1608Metric
C18, C19, C20, C21: 10u; C_0805_2012Metric
L1: 10u; L_APV_ANR8040
R21: 150k; R_0603_1608Metric
R22: 20k; R_0603_1608Metric
U7: AP63200WU; TSOT-23-6

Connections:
+12V: C14.1, C15.1, U7.2 (EN), U7.3 (IN); also elsewhere on the board
/Power Supply/AP63200-DCDC/SW: C16.2, L1.1, U7.5 (SW)
/Power Supply/AP63200-DCDC/Vout: C17.1, C18.1, C19.1, C20.1, C21.1, C22.1, L1.2, R21.1; also elsewhere on the board
GND: C14.2, C15.2, C18.2, C19.2, C20.2, C21.2, C22.2, R22.2, U7.4 (GND); also elsewhere on the board
unnamed: C16.1, U7.6 (BST)
unnamed: C17.2, R21.2, R22.1, U7.1 (FB)

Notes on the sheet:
6,8V

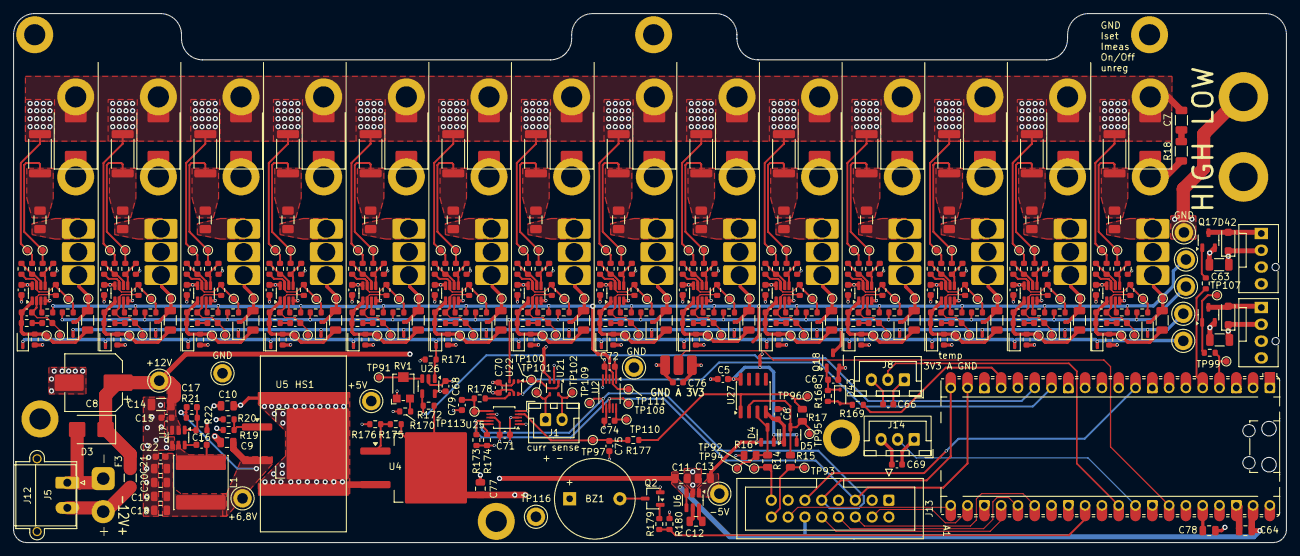
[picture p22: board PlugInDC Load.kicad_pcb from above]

Board: 4 copper layers, 192.5 x 80.0 mm, 525 parts (0 on the bottom side), 201 nets.

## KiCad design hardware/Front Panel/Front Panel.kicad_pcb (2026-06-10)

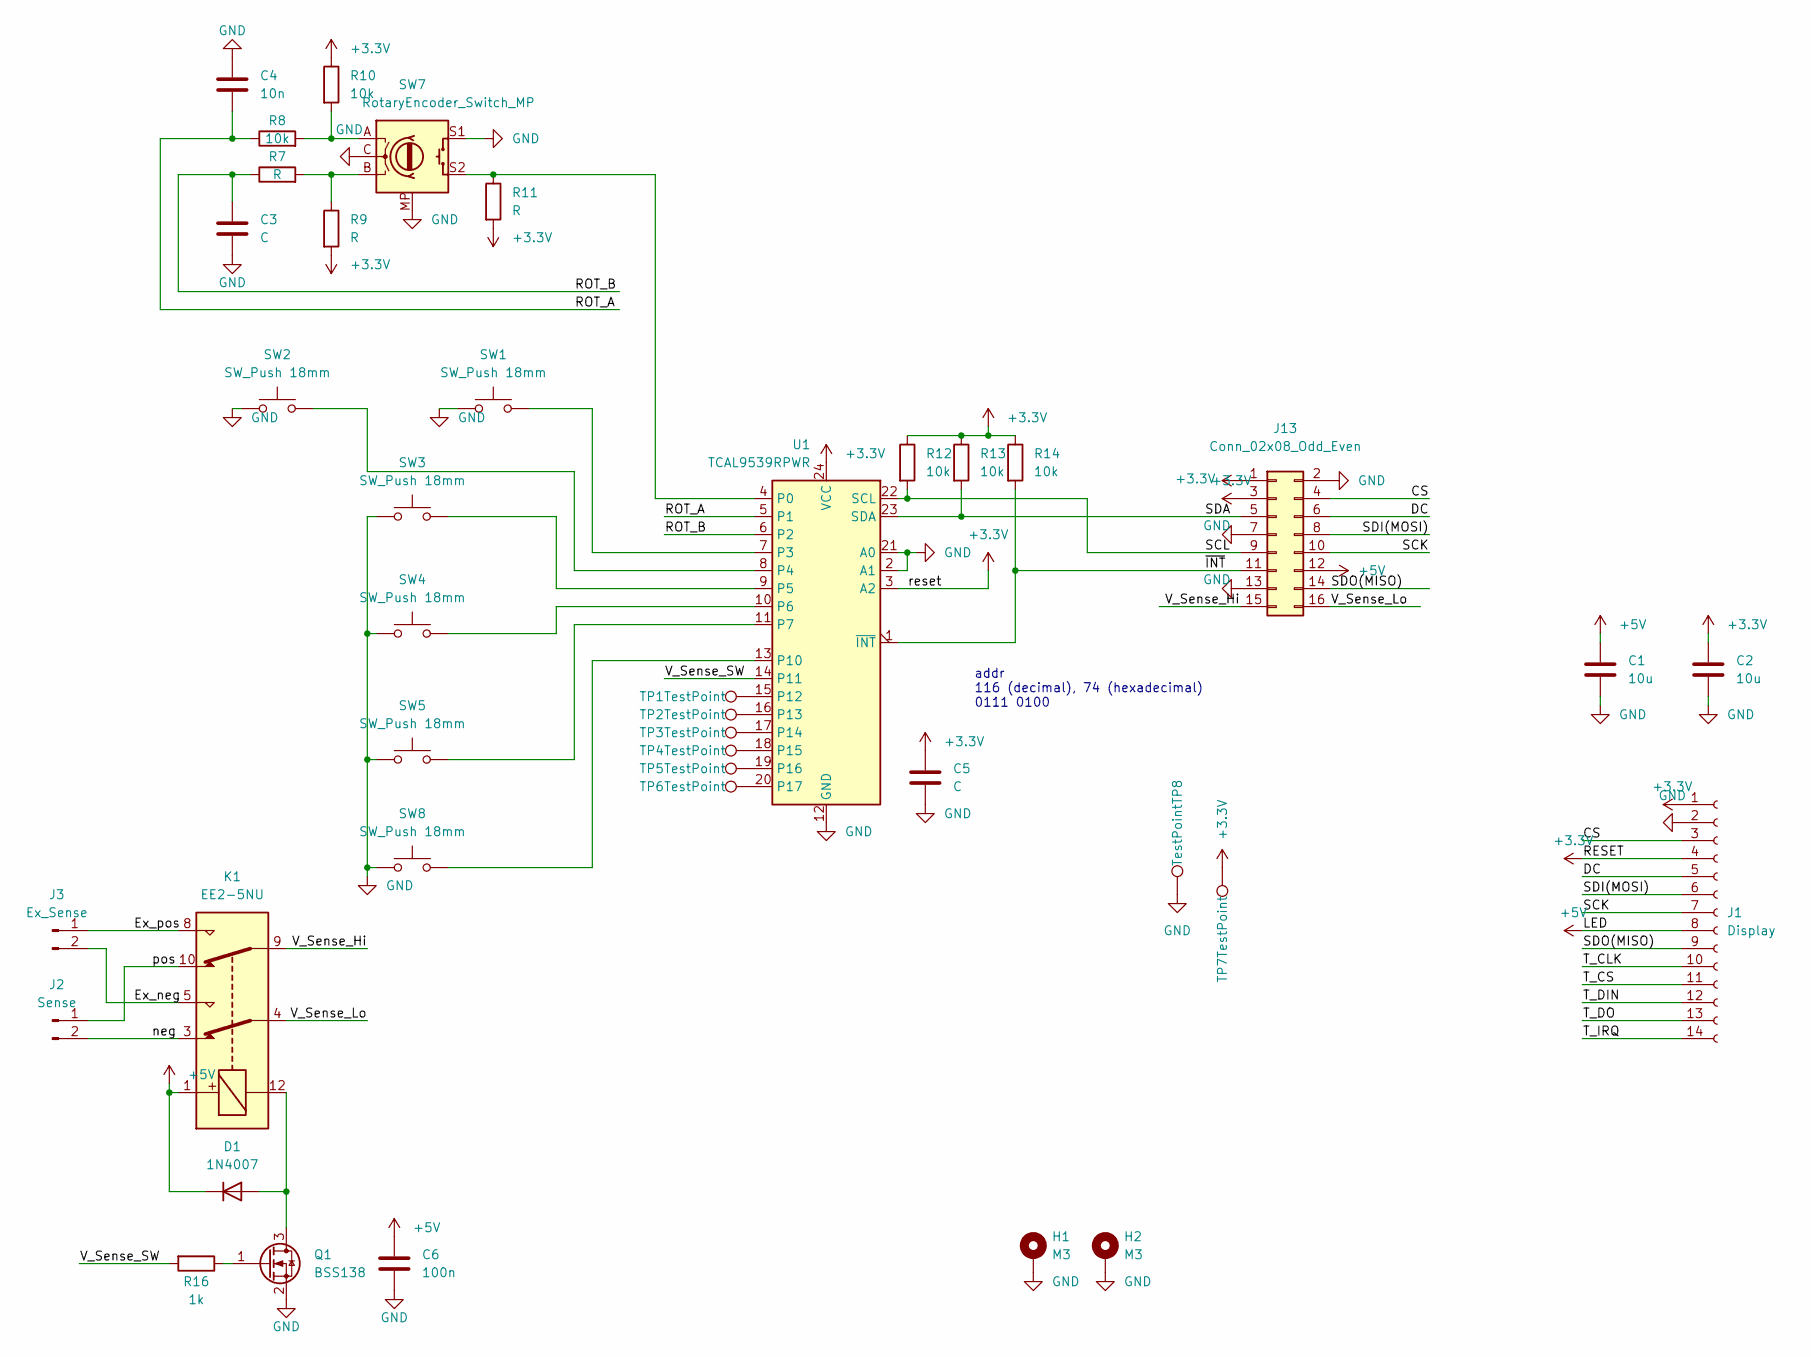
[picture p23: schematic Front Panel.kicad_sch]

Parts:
C1, C2: 10u
C3, C5: C
C4: 10n
C6: 100n
D1: 1N4007; D_SOD-123F
H1, H2: M3
J1: Display
J2: Sense
J3: Ex_Sense
J13: Conn_02x08_Odd_Even
K1: EE2-5NU; Relay_DPDT_Kemet_EE2_NU
Q1: BSS138; SOT-23
R7, R9, R11: R
R8, R10, R12, R13, R14: 10k
R16: 1k
SW1, SW2, SW3, SW4, SW5, SW8: SW_Push 18mm
SW7: RotaryEncoder_Switch_MP
TP1, TP2, TP3, TP4, TP5, TP6: TestPoint; TestPoint_Pad_D1.0mm
TP7, TP8: TestPoint; TestPoint_Pad_D1.5mm
U1: TCAL9539RPWR; TSSOP-24_4.4x7.8mm_P0.65mm

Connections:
+3.3V: C2.1, C5.1, J1.1, J1.4, J13.1, J13.3, R9.2, R10.1, R11.2, R12.1, R13.1, R14.1, TP7.1 (1_1), U1.3 (A2), U1.24 (VCC)
+5V: C1.1, C6.1, D1.1 (K), J1.8, J13.12, K1.1
/CS: J1.3, J13.4
/DC: J1.5, J13.6
/Ex_neg: J3.2, K1.5
/Ex_pos: J3.1, K1.8
/ROT_A: C4.1, R8.1, U1.5 (P1)
/ROT_B: C3.1, R7.1, U1.6 (P2)
/SCK: J1.7, J13.10
/SCL: J13.9, R12.2, U1.22 (SCL)
/SDA: J13.5, R13.2, U1.23 (SDA)
/SDI(MOSI): J1.6, J13.8
/SDO(MISO): J1.9, J13.14
/T_CLK: J1.10
/T_CS: J1.11
/T_DIN: J1.12
/T_DO: J1.13
/T_IRQ: J1.14
/V_Sense_Hi: J13.15, K1.9
/V_Sense_Lo: J13.16, K1.4
/V_Sense_SW: R16.2, U1.14 (P11)
/neg: J2.2, K1.3
/pos: J2.1, K1.10
/~INT: J13.11, R14.2, U1.1 (~INT)
GND: C1.2, C2.2, C3.2, C4.2, C5.2, C6.2, H1.1 (1_1), H2.1 (1_1), J1.2, J13.2, J13.7, J13.13, Q1.2 (S), SW1.1, SW2.1, SW3.1, SW4.1, SW5.1, SW7.C, SW7.MP, SW7.S1, SW8.1, TP8.1 (1_1), U1.2 (A1), U1.12 (GND), U1.21 (A0)
unnamed: D1.2 (A), K1.12, Q1.3 (D)
unnamed: Q1.1 (G), R16.1
unnamed: R7.2, R9.1, SW7.B
unnamed: R8.2, R10.2, SW7.A
unnamed: R11.1, SW7.S2, U1.4 (P0)
unnamed: SW1.2, U1.7 (P3)
unnamed: SW2.2, U1.8 (P4)
unnamed: SW3.2, U1.9 (P5)
unnamed: SW4.2, U1.10 (P6)
unnamed: SW5.2, U1.11 (P7)
unnamed: SW8.2, U1.13 (P10)
unnamed: TP1.1 (1_1), U1.15 (P12)
unnamed: TP2.1 (1_1), U1.16 (P13)
unnamed: TP3.1 (1_1), U1.17 (P14)
unnamed: TP4.1 (1_1), U1.18 (P15)
unnamed: TP5.1 (1_1), U1.19 (P16)
unnamed: TP6.1 (1_1), U1.20 (P17)

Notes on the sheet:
addr 116 (decimal), 74 (hexadecimal) 0111 0100

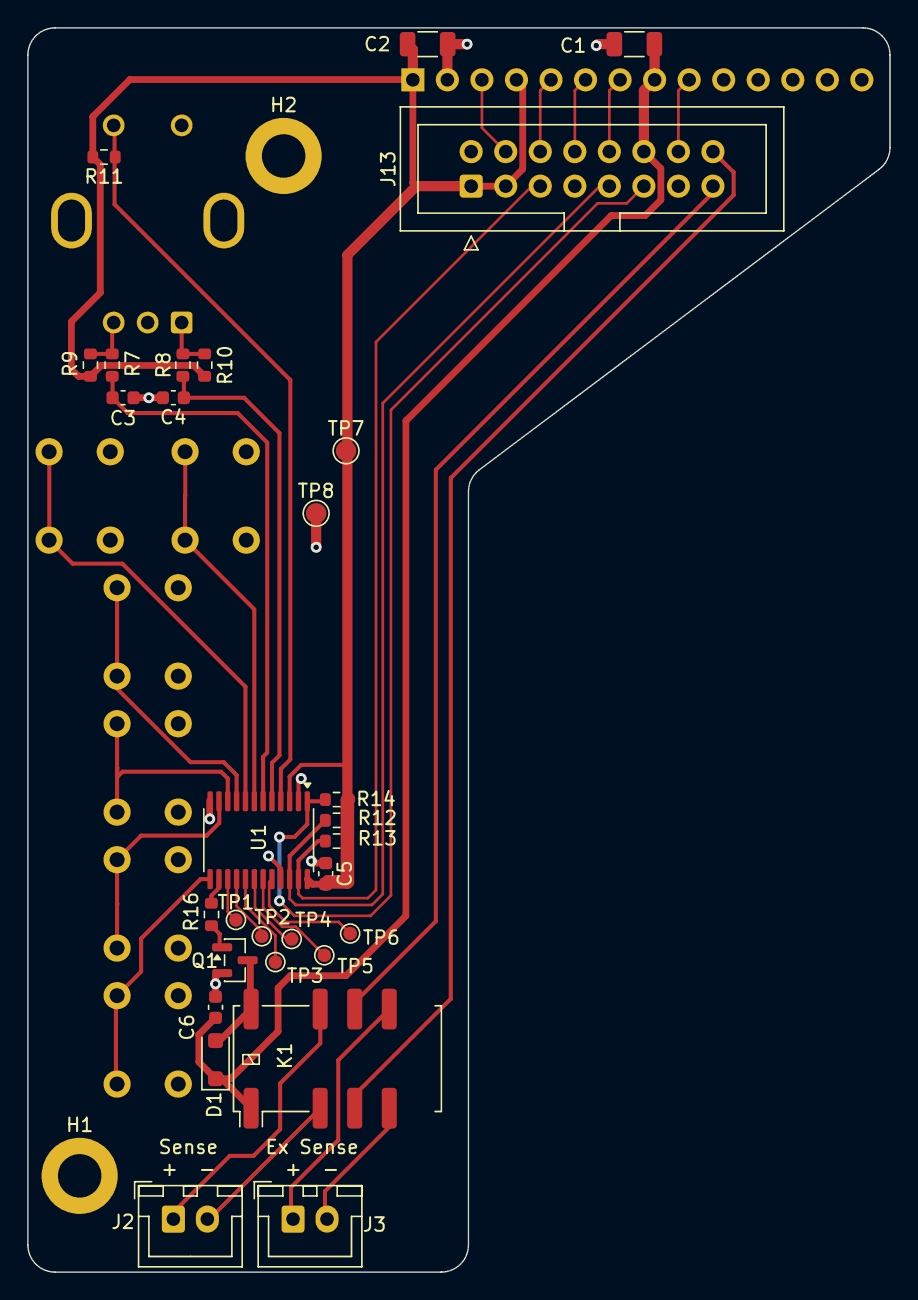
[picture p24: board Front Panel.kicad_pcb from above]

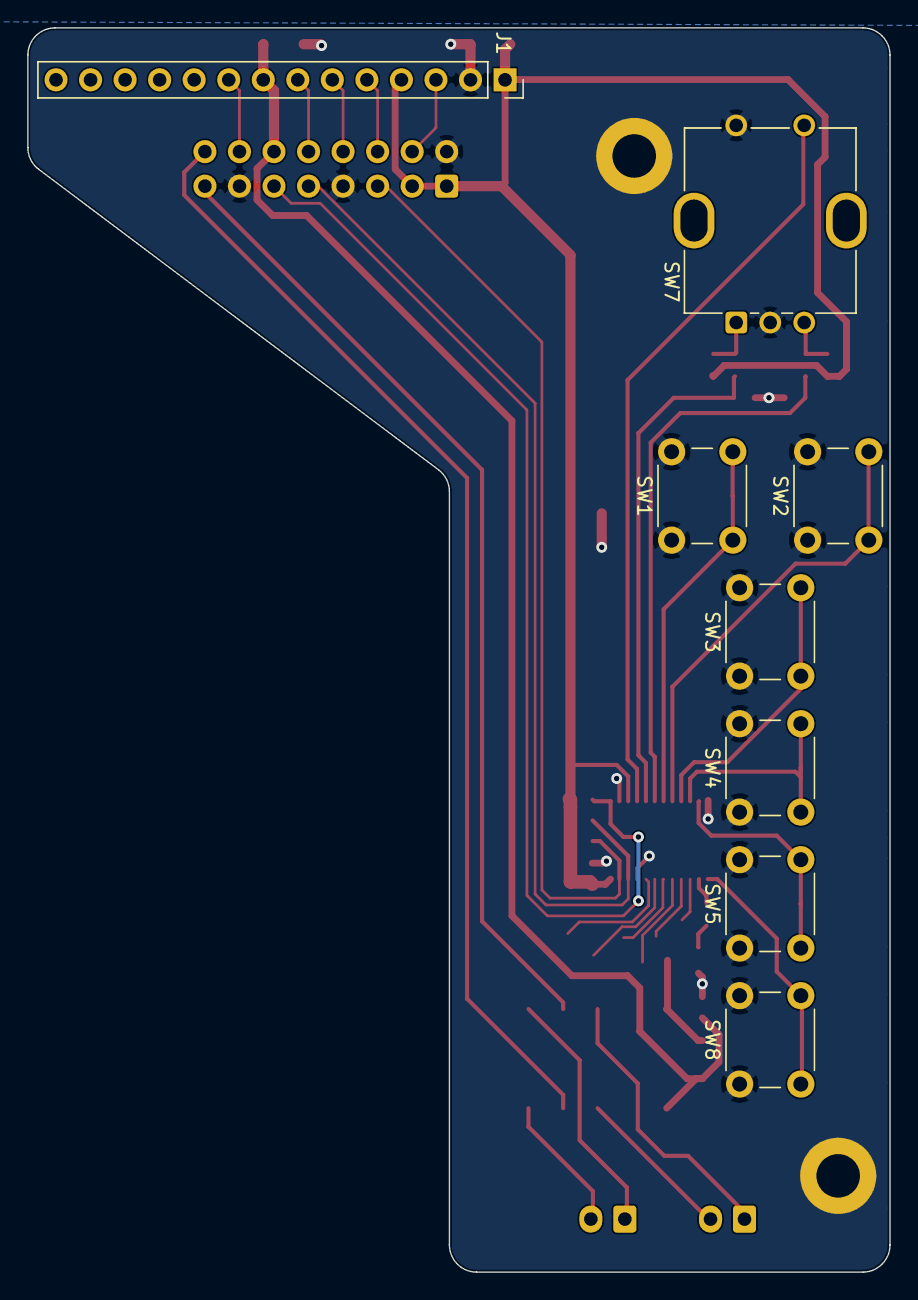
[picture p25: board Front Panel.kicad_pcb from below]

Board: 2 copper layers, 63.4 x 91.5 mm, 40 parts (8 on the bottom side), 37 nets.

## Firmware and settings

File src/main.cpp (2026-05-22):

#include <Arduino.h>
#include <Wire.h>
#include <TFT_eSPI.h>
#include <EEPROM.h>
#include "TCAL9539.h"

// EEPROM layout:
//   0       ISHUNT select (1 byte)
//   1       current cal valid marker (0xCA = valid)
//   2       voltage cal valid marker (0xCA = valid)
//   3..42   current cal: 5×rawA + 5×userA (10 floats = 40 bytes)
//   43..74  voltage cal: 4×rawV + 4×userV (8 floats = 32 bytes)
//   75      OTP valid marker (0xCA = valid)
//   76..79  OTP threshold (1 float = 4 bytes)
//   80      UVP PID valid marker (0xCA = valid)
//   81..84  UVP Kp (1 float = 4 bytes)
//   85..88  UVP Ki (1 float = 4 bytes)
#define EEPROM_SIZE              96
#define EEPROM_ADDR_ISHUNT        0
#define EEPROM_ADDR_CAL_A_VALID   1
#define EEPROM_ADDR_CAL_V_VALID   2
#define EEPROM_ADDR_CAL_RAW_A     3   // 5 floats (20 bytes)
#define EEPROM_ADDR_CAL_USER_A   23   // 5 floats (20 bytes)
#define EEPROM_ADDR_CAL_RAW_V    43   // 4 floats (16 bytes)
#define EEPROM_ADDR_CAL_USER_V   59   // 4 floats (16 bytes)
#define EEPROM_ADDR_OTP_VALID    75
#define EEPROM_ADDR_OTP_TEMP     76
#define EEPROM_ADDR_UVP_VALID    80
#define EEPROM_ADDR_UVP_KP       81
#define EEPROM_ADDR_UVP_KI       85

// ── DAC80501 ─────────────────────────────────────────────────────────────────
// Datasheet: SBAS794E (DAC80501/DAC70501/DAC60501)
// I2C address: SYNC/A0=GND → 1001 000 = 0x48
// Internal reference: 2.5 V
// GAIN reg resets to 0x0001 (BUFF-GAIN=1 → output gain=2 → full-scale = 5 V)
// REF-ALARM in STATUS reg forces output to 0 V when VREFIO headroom is too low
#define DAC80501_ADDR        0x48
#define DAC80501_REG_DEVID   0x01  // [14:12]=RESOLUTION, [7]=RSTSEL; 0x0115 = DAC80501Z
#define DAC80501_REG_CONFIG  0x03  // [8]=REF_PWDWN, [0]=DAC_PWDWN; reset=0x0000
#define DAC80501_REG_GAIN    0x04  // [8]=REF-DIV, [0]=BUFF-GAIN;   reset=0x0001
#define DAC80501_REG_STATUS  0x07  // [0]=REF-ALARM (1 → output forced to 0 V)
#define DAC80501_REG_DAC     0x08  // DAC-DATA[15:0], MSB-aligned;  reset=0x0000

static void dac80501Write(uint8_t reg, uint16_t val) {
    Wire1.beginTransmission(DAC80501_ADDR);
    Wire1.write(reg);
    Wire1.write(val >> 8);
    Wire1.write(val & 0xFF);
    Wire1.endTransmission();
}

static bool dac80501Read(uint8_t reg, uint16_t &out) {
    Wire1.beginTransmission(DAC80501_ADDR);
    Wire1.write(reg);
    if (Wire1.endTransmission(false) != 0) return false;
    if (Wire1.requestFrom((uint8_t)DAC80501_ADDR, (uint8_t)2) != 2) return false;
    out = ((uint16_t)Wire1.read() << 8) | Wire1.read();
    return true;
}

// Confirms I2C ACK and RESOLUTION bits [14:12] == 000b (16-bit DAC80501)
static bool dac80501Verify() {
    uint16_t devid;
    if (!dac80501Read(DAC80501_REG_DEVID, devid)) return false;
    return ((devid >> 12) & 0x7) == 0x0;
}

// ── ADS1115 ──────────────────────────────────────────────────────────────────
// I2C address: ADDR=VDD → 1001 001 = 0x49
// Config register (P[1:0]=01b) resets to 0x8583:
//   OS=1, MUX=000, PGA=010 (±2.048 V), MODE=1 (single-shot),
//   DR=100 (128 SPS), COMP_QUE=11 (disabled)
#define ADS1115_ADDR        0x49
#define ADS1115_REG_CONV    0x00  // conversion result (read after OS=1)
#define ADS1115_REG_CONFIG  0x01

// Base config words with PGA field zeroed; OR with (pga_idx << 9) at runtime.
// Single-shot, 128 SPS (DR=100b), comparator disabled (COMP_QUE=11b).
// Voltage: AIN0–AIN1 (MUX=000) → high=0x81, low=0x83
#define ADS1115_BASE_VOLT   0x8183
// Current: AIN2–AIN3 (MUX=011) → high=0xB1, low=0x83
#define ADS1115_BASE_CURR   0xB183

// 2.5 V on AIN0-AIN1 = 100 V on load input
#define ADS1115_V_SCALE     40.0f
// 2.5 V on AIN2-AIN3 = 100 A
#define ADS1115_I_SCALE     40.0f

// FSR for each PGA[2:0] index (0–5)
static const float kPgaFsr[] = {6.144f, 4.096f, 2.048f, 1.024f, 0.512f, 0.256f};
static uint8_t g_pgaV = 1;  // start at ±4.096 V (covers 2.5 V max on voltage channel)
static uint8_t g_pgaA = 2;  // start at ±2.048 V for current channel

static bool ads1115Write(uint8_t reg, uint16_t val) {
    Wire1.beginTransmission(ADS1115_ADDR);
    Wire1.write(reg);
    Wire1.write(val >> 8);
    Wire1.write(val & 0xFF);
    return Wire1.endTransmission() == 0;
}

static bool ads1115Read(uint8_t reg, uint16_t &out) {
    Wire1.beginTransmission(ADS1115_ADDR);
    Wire1.write(reg);
    if (Wire1.endTransmission(false) != 0) return false;
    if (Wire1.requestFrom((uint8_t)ADS1115_ADDR, (uint8_t)2) != 2) return false;
    out = ((uint16_t)Wire1.read() << 8) | Wire1.read();
    return true;
}

static bool ads1115Ping() {
    Wire1.beginTransmission(ADS1115_ADDR);
    return Wire1.endTransmission() == 0;
}

static bool ads1115Verify() {
    uint16_t cfg;
    if (!ads1115Read(ADS1115_REG_CONFIG, cfg)) return false;
    return cfg == 0x8583;
}

// Triggers a single-shot conversion with auto-ranging PGA.
// Returns NAN on I2C error. Blocks ~8 ms (one 128-SPS cycle).
// Thresholds: >87.5 % FS → lower gain; <43.75 % FS → higher gain (hysteresis gap prevents oscillation).
static float ads1115ReadChannel(uint16_t base_cfg, uint8_t &pga, float scale) {
    uint16_t cfg_word = base_cfg | ((uint16_t)pga << 9);
    if (!ads1115Write(ADS1115_REG_CONFIG, cfg_word)) return NAN;
    uint16_t cfg;
    uint32_t t = millis();
    do {
        if (!ads1115Read(ADS1115_REG_CONFIG, cfg)) return NAN;
    } while (!(cfg & 0x8000) && (millis() - t < 25));
    uint16_t raw;
    if (!ads1115Read(ADS1115_REG_CONV, raw)) return NAN;
    int16_t s = (int16_t)raw;
    float result = s * kPgaFsr[pga] / 32768.0f * scale;
    int16_t mag = s < 0 ? -s : s;
    if      (mag > 28671 && pga > 0) pga--;  // >87.5 % FS → lower gain next time
    else if (mag < 14335 && pga < 5) pga++;  // <43.75 % FS → higher gain next time
    return result;
}

static float ads1115ReadVoltage() {
    return ads1115ReadChannel(ADS1115_BASE_VOLT, g_pgaV, ADS1115_V_SCALE);
}

static float ads1115ReadCurrent() {
    return ads1115ReadChannel(ADS1115_BASE_CURR, g_pgaA, ADS1115_I_SCALE);
}

// Full-scale = 2 × (VREF/2) = 2.5 V  (REF-DIV=1 → VREFIO=1.25 V, BUFF-GAIN=1 → ×2)
// REF-DIV=1 is required on 3.3 V supply: without it VREFIO=2.5 V exceeds 0.5×VDD limit
// and REF-ALARM fires, forcing the output to 0 V.
static void dac80501SetVoltage(float v) {
    uint16_t code = (uint16_t)constrain(v / 2.5f * 65536.0f, 0, 65535);
    dac80501Write(DAC80501_REG_DAC, code);
}

#define PIN_SDA  14
#define PIN_SCL  15
#define PIN_INT   6

// Digital inputs
#define PIN_DIN_11  11

// Digital outputs
#define PIN_DOUT_2   2
#define PIN_DOUT_3   3
#define PIN_DOUT_8   8
#define PIN_DOUT_9   9
#define PIN_DOUT_10 10
#define PIN_DOUT_13 13
#define PIN_BEEPER  22

#define BTN_DEBOUNCE_MS 50

// Analog inputs (ADC0–ADC2 on RP2040)
#define PIN_ADC0    26
#define PIN_ADC1    27
#define PIN_ADC2    28

// MCP9700: V_out = 500 mV + 10 mV/°C; 2.5 V ADC reference, 10-bit counts
#define MCP9700_V0C    0.500f   // output at 0°C [V]
#define MCP9700_TC     0.010f   // temperature coefficient [V/°C]
#define MCP9700_VREF   2.5f     // ADC reference [V]
#define MCP9700_ADC_FS 1023.0f  // 10-bit full-scale count
#define MCP9700_T_MIN -10.0f    // below this → sensor absent/invalid [°C]
#define MCP9700_T_MAX  125.0f   // above this → sensor absent/invalid [°C]

TCAL9539 ioExp(Wire1);

volatile bool g_intPending = false;
void onTCALInt() { g_intPending = true; }

uint16_t      g_prevState    = 0xFFFF;
int8_t        g_cursorPos    = 3;      // 0=hundreds 1=tens 2=ones 3=tenths
bool          g_loadOn       = false;
bool          g_extVSense    = false;  // false = internal V-sense, true = external (FET on P11)
bool          g_extIShunt    = false;  // false = internal current sense (GPIO10 LOW), true = external shunt (GPIO10 HIGH)
bool          g_editUVP      = false;  // false = editing set current, true = editing UVP
int8_t        g_uvpCursorPos = 1;      // 0=tens 1=ones 2=tenths 3=hundredths
unsigned long g_timerElapsed  = 0;     // accumulated on-time [ms]; pauses while load is off
unsigned long g_timerSegStart = 0;     // millis() when the current on-segment started

TFT_eSPI    tft = TFT_eSPI();
TFT_eSprite spr = TFT_eSprite(&tft);

// Color palette — values are pre-inverted (~original) to compensate for
// TFT_INVERSION_ON on this ILI9488 panel. The display hardware inverts them
// back, so they render as the intended colours.
#define COL_BG       0xFFFF    // ~black   → appears black
#define COL_HDR_BG   0xFFF0    // ~0x000F  → appears dark navy
#define COL_DIV      0xD6BA    // ~0x2945  → appears dark grey
#define COL_LABEL    0x8410    // ~0x7BEF  → appears mid grey
#define COL_VOLT     0xF800    // ~cyan    → appears cyan
#define COL_CURR     0xF81F    // ~green   → appears green
#define COL_PWR      0x001F    // ~yellow  → appears yellow
#define COL_CAP      0x0841    // ~0xF7BE  → appears warm white
#define COL_SET      0x02DF    // ~0xFD20  → appears orange
#define COL_TEMP_OK  0x02DF    // ~0xFD20  → appears orange
#define COL_TEMP_HOT 0x07FF    // ~red     → appears red
#define COL_DBG_HDR_BG  0x057F  // ~0xFA80  → appears orange

// Portrait 240x320 — section Y positions and heights
//  Y    H   Section
//  0   24   header
//  24  62   voltage
//  86  62   current
// 148  62   power
// 210  40   capacity (left) | energy (right)
// 250  40   set curr (left) | set UVP (right)
// 290  30   heatsink temp
#define Y_HDR   0
#define Y_VOLT  24
#define Y_CURR  86
#define Y_PWR   148
#define Y_CAP   210
#define Y_SET   250
#define Y_TEMP  290

// Debug screen section Y positions (header 24 + 10×14 = 164 px; size-1 text = 8px/char)
#define Y_DBG_T0    24
#define Y_DBG_T1    38
#define Y_DBG_T2    52
#define Y_DBG_GPIO  66
#define Y_DBG_DAC   80
#define Y_DBG_ADS   94
#define Y_DBG_TCAL 108
#define Y_DBG_FAN  122
#define Y_DBG_VRAW   136
#define Y_DBG_IRAW   150
#define Y_DBG_ISENSE   164
#define Y_DBG_VSENSE   178
#define Y_DBG_CAL_V    192
#define Y_DBG_CAL_A    206
#define Y_DBG_CAL_VIEW 220
#define Y_DBG_OTP      234
#define Y_DBG_UVP_KP   248
#define Y_DBG_UVP_KI   262

// Dummy measurement values
float measV   = 12.34f;
float measA   = 5.678f;
float measW   = 0.0f;
float measAh  = 0.0f;
float measWh  = 0.0f;
float setA    = 6.000f;
float setUVP  = 0.00f;
float tempC   = 42.5f;
float g_tempAll[3]   = {NAN, NAN, NAN};
bool    g_debugScreen  = false;
bool    g_dacOk        = false;
bool    g_adsOk        = false;
bool    g_tcalOk       = false;
uint8_t g_fanPwm       = 0;

float g_rawV = 0.0f;   // last raw ads1115ReadVoltage() result (uncalibrated)
float g_rawA = 0.0f;   // last raw ads1115ReadCurrent() result (uncalibrated)

// Piecewise-linear calibration tables (loaded from EEPROM; identity by default)
float    g_calPtsRawA[5]  = { 0.0f, 0.5f,  2.0f, 10.0f, 60.0f };
float    g_calPtsUserA[5] = { 0.0f, 0.5f,  2.0f, 10.0f, 60.0f };
float    g_calPtsRawV[4]  = { 5.0f, 20.0f, 50.0f, 80.0f };
float    g_calPtsUserV[4] = { 5.0f, 20.0f, 50.0f, 80.0f };
bool     g_calACal        = false;   // true when a valid current cal is stored
bool     g_calVCal        = false;   // true when a valid voltage cal is stored
float    g_otpTemp        = 70.0f;   // over-temp protection threshold [°C]
bool     g_otpTriggered   = false;   // true after OTP fires; clears when temp < threshold-5°C

uint8_t       g_beepCount = 0;       // OTP alarm: remaining beeps (0 = idle)
bool          g_beepPhase = false;   // current beep phase: true = ON
unsigned long g_beepNext  = 0;       // millis() of next beep state change

// UVP constant-voltage control loop
float    g_uvpKp       = 5.0f;    // proportional gain [A/V]
float    g_uvpKi       = 0.2f;    // integral gain [A/(V·s)]
float    g_uvpIntegral = 0.0f;    // integral accumulator
bool     g_uvpActive   = false;   // true while CV regulation is active

// Calibration UI (scratch space used during the calibration procedure)
enum CalMode : uint8_t { CAL_NONE = 0, CAL_CURR = 1, CAL_VOLT = 2 };
CalMode  g_calMode      = CAL_NONE;
uint8_t  g_calStep      = 0;
float    g_calUserVal   = 0.0f;
int8_t   g_calCursor    = 0;
float    g_calRaw[5];
float    g_calUser[5];
bool     g_calSavedLoad  = false;
float    g_calSavedSetA  = 0.0f;
bool     g_calViewScreen = false;
int8_t   g_dbgMenuSel    = -1;     // -1=none, 0=VOLT CAL, 1=CURR CAL, 2=VIEW CAL

enum AppMode : uint8_t { MODE_NORMAL = 0, MODE_ESR = 1 };
static const char* kMenuLabels[] = { "NORMAL LOAD", "ESR MEASURE" };
AppMode  g_appMode  = MODE_NORMAL;
bool     g_menuOpen = false;
uint8_t  g_menuSel  = 0;

float    g_esrImax      = 0.0f;   // ESR I max setpoint [A]
float    g_esrImin      = 0.0f;   // ESR I min setpoint [A]
bool     g_esrEditMin   = false;  // false=cursor on I max, true=cursor on I min
int8_t   g_esrCursorMax = 3;      // cursor digit for I max (0=hundreds … 3=tenths)
int8_t   g_esrCursorMin = 3;      // cursor digit for I min
uint8_t  g_esrStep      = 0;              // ESR cycle step 0-9
float    g_esrSumV[2]   = {0.0f, 0.0f};  // V accumulator [0=Imax phase, 1=Imin phase]
float    g_esrSumI[2]   = {0.0f, 0.0f};  // I accumulator
float    g_esrDeltaV    = NAN;            // last Vmax - Vmin
float    g_esrDeltaI    = NAN;            // last Imax_meas - Imin_meas
float    g_esrResult    = NAN;            // last ESR [Ohm]

static const float   kCalCurrSetPt[]  = { 0.0f, 0.5f, 2.0f, 10.0f, 60.0f };
static const uint8_t kCalCurrNPts     = 5;
static const uint8_t kCalVoltNPts     = 4;
static const float   kCalStep[]       = { 10.0f, 1.0f, 0.1f, 0.01f, 0.001f };
static const uint8_t kCalNDigits      = 5;
static const uint8_t kCalCharIdx[]    = { 0, 1, 3, 4, 5 };

// Piecewise linear interpolation through n points (xs must be monotone increasing).
// Extrapolates linearly beyond the endpoints using the adjacent segment.
static float piecewiseLerp(const float *xs, const float *ys, uint8_t n, float x) {
    if (n < 2) return x;
    uint8_t lo = 0, hi = n - 1;
    if (x <= xs[lo]) { lo = 0; hi = 1; }
    else if (x >= xs[hi]) { lo = n - 2; hi = n - 1; }
    else { for (uint8_t i = 0; i < n - 1; i++) if (x <= xs[i+1]) { lo = i; hi = i+1; break; } }
    float dx = xs[hi] - xs[lo];
    return fabsf(dx) < 1e-9f ? ys[lo] : ys[lo] + (x - xs[lo]) * (ys[hi] - ys[lo]) / dx;
}

// 100 A → 2.5 V; DAC always tracks setpoint, load on/off is handled by a separate enable signal
static void applySetCurrent() {
    // Inverse map: desired actual current → nominal DAC setpoint.
    // Forward cal: kCalCurrSetPt[i] (nominal) → g_calPtsUserA[i] (measured actual).
    // Inverse: use userA as x-axis, nominal setpoints as y-axis.
    float nominal = g_calACal
        ? piecewiseLerp(g_calPtsUserA, kCalCurrSetPt, kCalCurrNPts, setA)
        : setA;
    dac80501SetVoltage(constrain(nominal, 0.0f, 100.0f) / 100.0f * 2.5f);
}

static void applyCurrentDirect(float amps) {
    float nominal = g_calACal
        ? piecewiseLerp(g_calPtsUserA, kCalCurrSetPt, kCalCurrNPts, amps)
        : amps;
    dac80501SetVoltage(constrain(nominal, 0.0f, 100.0f) / 100.0f * 2.5f);
}

static void loadCalParams() {
    if (EEPROM.read(EEPROM_ADDR_CAL_A_VALID) == 0xCA) {
        for (uint8_t i = 0; i < kCalCurrNPts; i++) {
            EEPROM.get(EEPROM_ADDR_CAL_RAW_A  + i * 4, g_calPtsRawA[i]);
            EEPROM.get(EEPROM_ADDR_CAL_USER_A + i * 4, g_calPtsUserA[i]);
        }
        g_calACal = true;
    }
    if (EEPROM.read(EEPROM_ADDR_CAL_V_VALID) == 0xCA) {
        for (uint8_t i = 0; i < kCalVoltNPts; i++) {
            EEPROM.get(EEPROM_ADDR_CAL_RAW_V  + i * 4, g_calPtsRawV[i]);
            EEPROM.get(EEPROM_ADDR_CAL_USER_V + i * 4, g_calPtsUserV[i]);
        }
        g_calVCal = true;
    }
    if (EEPROM.read(EEPROM_ADDR_OTP_VALID) == 0xCA) {
        EEPROM.get(EEPROM_ADDR_OTP_TEMP, g_otpTemp);
        g_otpTemp = constrain(g_otpTemp, 30.0f, 120.0f);
    }
    if (EEPROM.read(EEPROM_ADDR_UVP_VALID) == 0xCA) {
        EEPROM.get(EEPROM_ADDR_UVP_KP, g_uvpKp);
        EEPROM.get(EEPROM_ADDR_UVP_KI, g_uvpKi);
        g_uvpKp = constrain(g_uvpKp, 0.0f, 100.0f);
        g_uvpKi = constrain(g_uvpKi, 0.0f,  10.0f);
    }
}

static void saveUvpParams() {
    EEPROM.write(EEPROM_ADDR_UVP_VALID, 0xCA);
    EEPROM.put(EEPROM_ADDR_UVP_KP, g_uvpKp);
    EEPROM.put(EEPROM_ADDR_UVP_KI, g_uvpKi);
    EEPROM.commit();
}

static void saveOtpTemp() {
    EEPROM.write(EEPROM_ADDR_OTP_VALID, 0xCA);
    EEPROM.put(EEPROM_ADDR_OTP_TEMP, g_otpTemp);
    EEPROM.commit();
}

static void saveCalParams() {
    for (uint8_t i = 0; i < kCalCurrNPts; i++) {
        EEPROM.put(EEPROM_ADDR_CAL_RAW_A  + i * 4, g_calPtsRawA[i]);
        EEPROM.put(EEPROM_ADDR_CAL_USER_A + i * 4, g_calPtsUserA[i]);
    }
    for (uint8_t i = 0; i < kCalVoltNPts; i++) {
        EEPROM.put(EEPROM_ADDR_CAL_RAW_V  + i * 4, g_calPtsRawV[i]);
        EEPROM.put(EEPROM_ADDR_CAL_USER_V + i * 4, g_calPtsUserV[i]);
    }
    EEPROM.write(EEPROM_ADDR_CAL_A_VALID, g_calACal ? 0xCA : 0x00);
    EEPROM.write(EEPROM_ADDR_CAL_V_VALID, g_calVCal ? 0xCA : 0x00);
    EEPROM.commit();
}

static float readMCP9700(uint8_t pin) {
    float v = analogRead(pin) * (MCP9700_VREF / MCP9700_ADC_FS);
    float t = (v - MCP9700_V0C) / MCP9700_TC;
    return (t >= MCP9700_T_MIN && t <= MCP9700_T_MAX) ? t : NAN;
}

// ── Primitives ───────────────────────────────────────────────────────────────

void drawVSenseIndicator() {
    tft.setTextDatum(TL_DATUM);
    tft.setTextSize(1);
    tft.setTextColor(g_extVSense ? COL_VOLT : COL_LABEL, COL_BG);
    tft.drawString(g_extVSense ? "EXT" : "INT", 92, Y_VOLT + 6);
}
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
void loop() {
    // ~1 µs when idle; ~2.4 ms when interrupt fired (TCAL9539 I2C readPorts over Wire1 @ 1 MHz)
    handleInputs();

    static unsigned long lastUpdate = 0;
    static unsigned long lastTempUpdate = 0;
    unsigned long now = millis();
    updateBeeper(now);

    if (now - lastTempUpdate >= 1000) {
        lastTempUpdate = now;
        g_tempAll[0] = readMCP9700(PIN_ADC0);
        g_tempAll[1] = readMCP9700(PIN_ADC1);
        g_tempAll[2] = readMCP9700(PIN_ADC2);
        float tMax = NAN;
        for (float ti : g_tempAll) if (!isnan(ti) && (isnan(tMax) || ti > tMax)) tMax = ti;
        if (!isnan(tMax)) tempC = tMax;
        // OTP: shut load off and trigger alarm when threshold exceeded
        if (!g_otpTriggered && !isnan(tempC) && tempC >= g_otpTemp) {
            g_otpTriggered = true;
            if (g_loadOn) {
                g_timerElapsed += millis() - g_timerSegStart;
                g_loadOn = false;
                digitalWrite(PIN_DOUT_13, HIGH);
                dac80501SetVoltage(0);
                if (!g_debugScreen && !g_calViewScreen && g_calMode == CAL_NONE) drawHeader();
            }
            g_beepCount = 5;
            g_beepPhase = false;
            g_beepNext  = now;
        } else if (g_otpTriggered && tempC < g_otpTemp - 5.0f) {
            g_otpTriggered = false;
        }
        // off below 30°C, linear ramp to 100% at 50°C
        g_fanPwm = (uint8_t)constrain((tempC - 30.0f) / 20.0f * 255.0f, 0.0f, 255.0f);
        analogWrite(PIN_DOUT_2, g_fanPwm);
        analogWrite(PIN_DOUT_3, g_fanPwm);
        if (g_debugScreen) {
            g_dacOk  = dac80501Verify();
            g_adsOk  = ads1115Ping();
            g_tcalOk = ioExp.ping();
            updateDebugValues();
        }
    }

    if (now - lastUpdate >= 100) {
        float dtH = (now - lastUpdate) / 3600000.0f;
        lastUpdate = now;
        float v = ads1115ReadVoltage();   // ~8 ms — one 128-SPS single-shot conversion period
        if (!isnan(v)) { g_rawV = v; measV = g_calVCal ? piecewiseLerp(g_calPtsRawV, g_calPtsUserV, kCalVoltNPts, v) : v; }
        handleInputs();

        float a = ads1115ReadCurrent();   // ~8 ms — same
        if (!isnan(a)) { g_rawA = a; measA = g_calACal ? piecewiseLerp(g_calPtsRawA, g_calPtsUserA, kCalCurrNPts, a) : a; }
        handleInputs();

        measW = measV * measA;
        if (g_loadOn && g_appMode == MODE_NORMAL) {
            measAh += measA * dtH;
            measWh += measW * dtH;
        }
        if (g_appMode == MODE_ESR && g_loadOn) esrTick();

        // UVP constant-voltage control loop — normal mode only
        if (g_appMode == MODE_NORMAL) {
            if (g_loadOn && setUVP > 0.0f) {
                float error = measV - setUVP;  // positive = above threshold, negative = below
                bool wasActive = g_uvpActive;
                if (!g_uvpActive && error < 0.0f) {
                    g_uvpActive   = true;
                    g_uvpIntegral = 0.0f;
                }
                if (g_uvpActive) {
                    // Anti-windup: integral only accumulates in the negative (reducing) direction
                    g_uvpIntegral = constrain(
                        g_uvpIntegral + g_uvpKi * error * (dtH * 3600.0f),
                        -setA, 0.0f);
                    float cv_current = setA + g_uvpKp * error + g_uvpIntegral;
                    applyCurrentDirect(constrain(cv_current, 0.0f, setA));
                    // Exit CV mode with 0.5V hysteresis to avoid chattering
                    if (error > 0.5f) {
                        g_uvpActive   = false;
                        g_uvpIntegral = 0.0f;
                        applySetCurrent();
                    }
                }
                if (g_uvpActive != wasActive && !g_debugScreen && !g_calViewScreen && g_calMode == CAL_NONE) {
                    drawSetUVP();
                }
            } else if (g_uvpActive) {
                // UVP disabled (setUVP==0) or load turned off — exit CV mode
                g_uvpActive   = false;
                g_uvpIntegral = 0.0f;
                if (g_loadOn) applySetCurrent();
                if (!g_debugScreen && !g_calViewScreen && g_calMode == CAL_NONE) drawSetUVP();
            }
        }

        if      (g_calMode != CAL_NONE) updateCalScreen();
        else if (!g_debugScreen && !g_calViewScreen && !g_menuOpen) {
            if (g_appMode == MODE_NORMAL) updateValues();
            else updateEsrValues();
        }
    }
}

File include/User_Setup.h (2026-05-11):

// User setup for TFT_eSPI library - Raspberry Pi Pico with SPI display

#ifndef USER_SETUP_H_INCLUDED
#define USER_SETUP_H_INCLUDED

// ===========================
// Display Model Configuration
// ===========================
// Uncomment your display model:
//#define ILI9341_DRIVER       // 2.4" ILI9341 SPI display
 #define ILI9488_DRIVER    // 3.5" ILI9488 SPI display  
// #define ST7735_DRIVER     // 1.8" ST7735 SPI display
// #define ST7789_DRIVER     // 1.3" ST7789 SPI display

// ===========================
// SPI Pin Configuration for Raspberry Pi Pico
// ===========================
#define TFT_MOSI 19    // GPIO19
#define TFT_MISO 16    // GPIO16
#define TFT_SCLK 18    // GPIO18
#define TFT_CS   17    // GPIO17 (Chip Select)
#define TFT_DC   20    // GPIO20 (Data/Command)
#define TFT_RST  -1    // Set to -1 if RST is connected to 3.3V

// Optional: backlight pin (set to -1 if not using)
#define TFT_BL   -1    // Backlight control pin

// ===========================
// SPI Speed
// ===========================
#define SPI_FREQUENCY  75000000    // 75 MHz - RP2350 max (sys_clk 150 MHz / 2)

// ===========================
// Display Orientation and Size
// ===========================
#define TFT_WIDTH  240   // confirmed by hardware
#define TFT_HEIGHT 320   // confirmed by hardware
// ===========================
// Font Smoothing
// ===========================
#define SMOOTH_FONT

// ===========================
// Color Order
// ===========================
// ILI9488 panels sometimes ship with BGR order instead of RGB.
// If blue appears as red (or vice versa), swap this define.
#define TFT_RGB_ORDER TFT_RGB
#define TFT_INVERSION_ON   // try TFT_RGB if colors are still wrong


// ===========================
// Library Options
// ===========================
#define SUPPORT_TRANSACTIONS

#endif // USER_SETUP_H_INCLUDED

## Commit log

2026-05-11 Remove .pio from tracking and add to .gitignore
    PlatformIO build cache and downloaded library dependencies should not
    be committed — they are regenerated by `pio run`.
2026-05-11 Add fan PWM % to debug screen, normalize temp text size
    - Promote fanPwm to g_fanPwm global so debug screen can read it
    - Add FAN PWM row to debug screen showing percentage (0-100%)
    - Change temp values from textSize 3 to 2, matching all other debug rows
    - Shrink temp sections from 50px to 35px; screen no longer forced to fill
    [main.cpp]
2026-05-11 Add raw ADC voltages and PGA state to debug screen
    Add V RAW and I RAW rows showing the ADS1115 input voltage (scaled
    measurement / 40) and the current auto-range PGA index (P0–P5).
    Shrink all debug sections from 35px to 28px to fit two extra rows
    within the 320px display height.
2026-05-11 Optimise display updates and add measured loop timings as comments
    Reduce sprite alloc/free cycles in updateValues() from 7 to 3 by
    reusing a single sprite per row group (V/A/W share 230x26, Ah/Wh
    share 110x16, temp+timer combined into one 182x18 with divider
    embedded). Drops display time from ~14.2 ms to ~13.8 ms per cycle.
    Add measured timings as comments: handleInputs ~1 µs idle / ~2.4 ms
    on interrupt, each ADS1115 read ~15.5 ms (64-SPS single-shot),
    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
2026-05-11 Fix debug screen input handling and add EEPROM-backed shunt selection
    - Ignore encoder rotation, left/right arrow keys on debug screen to prevent
    accidental set-current/UVP edits
    - Guard drawVSenseIndicator() behind !g_debugScreen to avoid overwriting
    debug screen content
    - Persist ext/int shunt selection to EEPROM; restore on boot via GPIO10
    - Add I SENSE row to debug screen showing current shunt mode
    - Encoder push on debug screen toggles int/ext shunt (previously toggled UVP edit)
    [main.cpp]
2026-05-15 added OTP and calibration
2026-05-15 add UVP CV mode with software PI control loop
    When setUVP > 0V and measured voltage drops below the threshold, the load
    switches to constant-voltage mode by reducing current via a PI controller
    instead of shutting off. Current is always capped at the user-set setA.
    UVP Kp and Ki are tunable and EEPROM-persisted via two new debug screen rows.
    UVP display turns red while CV regulation is active. setUVP defaults to 0V
    (disabled).
2026-05-15 added button debounce and more cal points for volatage
2026-05-15 update README to reflect current firmware features
    - Fix fan control thresholds (30–50 °C, was 35–55 °C)
    - Add UVP/CV mode section (software PI constant-voltage control)
    - Add OTP section (threshold, shutoff, beep alarm, auto-recovery)
    - Expand controls into context-sensitive tables for main/debug/cal screens
    - Document debug screen as navigable menu with all 7 items
    - Add calibration wizard and EEPROM layout sections
2026-05-22 add ESR measurement mode with mode selection menu
    - P0.7 opens a mode selection overlay (NORMAL LOAD / ESR MEASURE),
    navigated with left/right arrows and confirmed with encoder button
    - ESR screen: compact 2x2 grid (V, A, W, ESR) at top; delta V display;
    I max / I min digit-cursor editors (same style as set-current/UVP)
    - ESR measurement loop: 1 Hz switching between Imin and Imax, four
    calibrated V/I samples per half-cycle (100 ms apart), averages used
    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
2026-06-10 Add hardware: KiCad design files for PlugInDC Load and Front Panel
    Add the two KiCad projects under hardware/ (design source only:
    schematics, PCB, schematic PDF, STEP model, iBOM). Backups, local
    history, caches, library tables and fabrication outputs are excluded
    via hardware/.gitignore.
    Document the board design in the README.
    [AP63200-DCDC.kicad_sch, BlockDiagramm.kicad_sch, DAC_ADC.kicad_sch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]
